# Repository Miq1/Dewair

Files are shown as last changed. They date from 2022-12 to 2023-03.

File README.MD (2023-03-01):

## Multi-purpose environment sensor device

DewAir was originally created to measure temperatures, humidity and dew point inside and outside a room and 
control a ventilator to dry out the room. 
It has been modified in the meantime to accomodate other functions as temperature alarm, remote weather sensor etc.

For this purpose it can be equipped with none, one or two DHT22 sensors, either plugged into the device or detached by a 3-wire cable.
Control over the vent is provided by a relais connected locally or over Modbus TCP to remotely switch a socket.

The device can be configured with a built-in HTML page or over Modbus TCP.
The latter also allows for data retrieval and maintenance. 
If more than one DewAir device is used, one can retrieve the sensor data from another over Modbus TCP, thus saving sensors. 

Power is supplied by USB or 5V, sensors and relais driver are powered internally.
Power consumption is below 90mA normally.

For schematics, PCB designs and 3D printable enclosures see the "Extras" folder.

### Installation

### Usage instructions

#### Start sequence
If powered on, the device will execute some initial steps until reaching normal function.
If it never was configured before (no valid configuration data found) it will immediately start Configuration mode (see next section). 
This is indicated by a slow triple blink pattern of the status LED.

Else there is a short (3s) fast blinking period. If you will press the button within this time, Configuration mode will be entered unconditionally.

Next configuration data is read, a WiFi connection is attempted with the given SSID and password. A fastly blinking LED will signal it.
Once a connection is established, both sensors are checked. If a sensor is found reacting the respective LED will turn on.

At this point the regular state is reached.

#### Configuration mode
In Configuration mode, the device will span its own WiFi network with a name of "DewAir-xxxxxx" and the given password in the source. This by default is "Maelstrom".

You will have to connect to that network to get access to the configuration. Please note that this WiFi is unencrypted and should not be kept online for too long.

Next you will want to open a browser to call the configuration HTML page with URL ``http://192.168.4.1/``. Note again that this is without TLS, so use ``http://``, not "https"!

The configuration page has several parts, described top to bottom below. Most input fields have minimum and maximum values that you may see if hovering over it with your mouse pointer.
The configuration may be invisible in parts at the first time, necessary detail input fields will be swapped in or out depending on your settings.

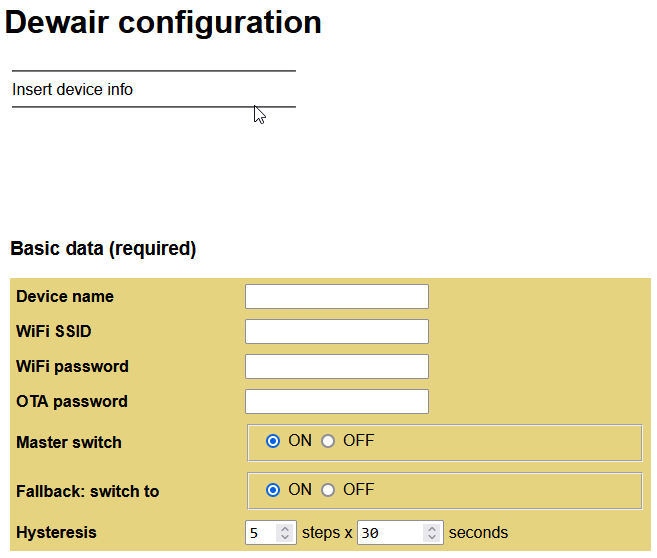
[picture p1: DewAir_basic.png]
Basic data

The most important part is the first, where you will have to enter a name of the new device and the WiFi credentials of your local WiFi for the device to connect to.
Below that you may give an OTA password in case you are planning to update the firmware over air.

The next is the "master switch". This is used to completely switch the logic and target switching on or off. With it you may temporarily disable the device's activities for re-configuration etc. It is advisable to leave it OFF for the first time you are configuring it to be able to cross-check your configurations before going live.

Next comes the "fallback policy". This is to set a default target state in case the sensors or logic will fail at some time.
If set to ON, a failure will drive the device to unconditionally switch the target to ON.
The device logic may be resumed as soon as the causing failure is gone again.
The advisable state of the fallback switch is totally up to you and your application. A frost protector f.i. may better be switched ON, while a motorized door may have to be OFF instead.

Finally the "hysteresis" can be adjusted. Hysteresis means defining a number of necessary, consecutive measurements, whose results have lead to the same logic decision to switch the target.
Hysteresis consists of two components: a number of measurements in a row necessary and the time between measuring actions.
To give an example: a number of 5 measurements and a time of 20s will require the logic to decide the same for all 5 checks in 100s.
Only if all 5 resulted in either all ON or all OFF decisions, the switch finally will be done, if applicable.
The intended result is a less "nervous", steady switching behaviour that does not react on single dropout measurements.

Target configuration
The target definition is required should you want to physically switch something on or off based on the sensor data.
If the device is used as a temp/humidity sensor only, the target may be left unconfigured.
A target may be one of three variants: "ignore", if not relevant as described before, "connected", if the device's relay port is used for it, or "Modbus" for a remote "[Smartdose](https://github.com/eModbus/Smartdose)" socket addressed via Modbus.
To use the latter, the TCP IP address, Modbus port number and Modbus server ID for it are required.

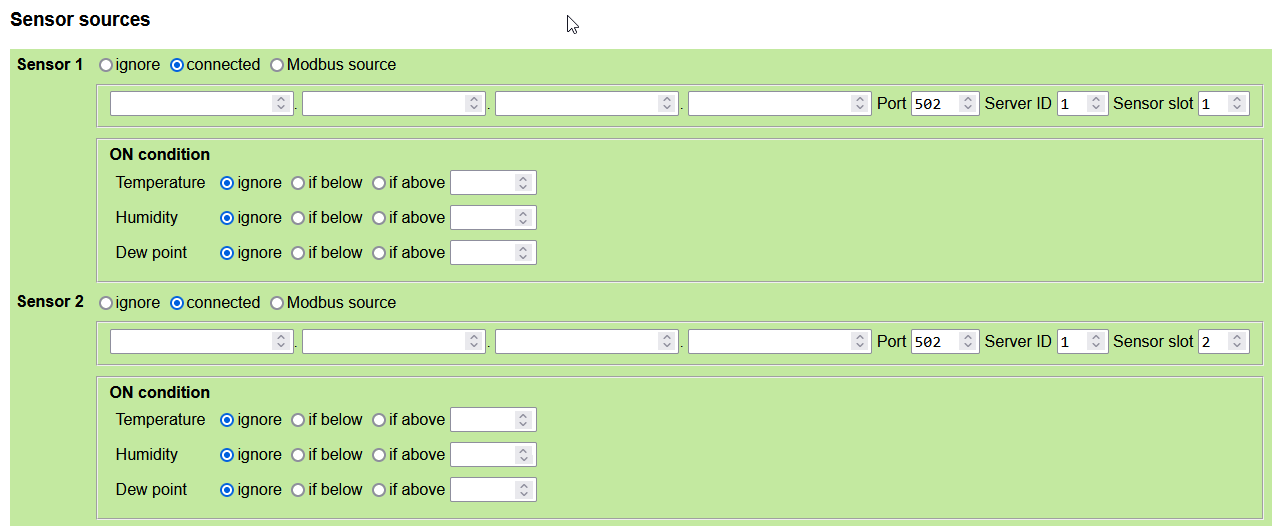
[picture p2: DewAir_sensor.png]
Sensors configuration

Sensor configuration is quite similar to that of the target device.
The "ignore" option leaves the respective sensor slot unregarded. At the same time the combo conditions (see below) will vanish, since 
these only make sense with two sensors present.

The data for a remote, Modbus-connected sensor are the same as before for the target, with one addition: sensor slot.
A remote sensor must reside in another DewAir device to be addressed. As there are two sensor slots, you will need to name the one you are referring to.

A typical application for a remote sensor is to have just one sensor outside the building and all other devices inside it referring to the values of that one sensor.

The conditions section allows to set the conditions the respective sensor must detect to enable the target to be switched on.
Temperature, humidity or dew point can be addressed separately, the results of the evaluations are combined by a logical "and".
If you f.i. want to switch the target on a temperature higher than 10&#176;C and do not care about humidity or dew point, you will want to click on "above" in the temperature line and enter a value of 10 in the data input field. 
Both humidity and dew point options need to be set to "ignore".

Conditions set for a device that later was set to "ignore" as a device will remain unconsidered.

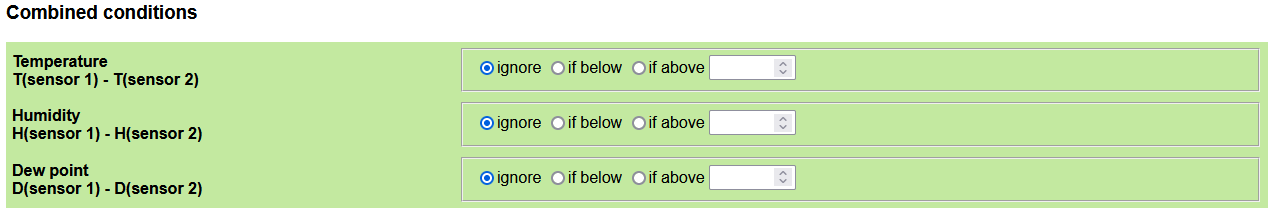
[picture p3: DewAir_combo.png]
Combo conditions

Likewise the combination conditions can be set. There always is a difference of the respective measurement of sensors S0 and S1 taken as the criteria for the conditions.
The settings for the conditions are identical to those with the individual sensor conditions.

#### LED decoding
There are four LEDs on the device in this order: status, S0, S1 and target. 
I recommend to use a different LED color for the status LED for better recognition.

##### Status LED
It will signal the general state the device is in. The start sequence is described above.

In manual mode the status LED will be steadily on, the target LED will show the switch state of the target.

If the target is supposed to be off as result of the evaluation of the conditions, the status LED will display a slow single blinking pattern.

Else, if the target is to be on, the status LED will send a triple blink with a pause in between.

Whenever a measurement is initiated, the status LED will turn on and off after it.

##### Sensor LEDs S0/S1
The respective sensor LED will turn on, if the sensor was configured and a measurement was successful.
A sensor not configured will be displayed by its LED being constantly off.

If a sensor was not responding, the LED will start blinking very quickly. It will resume the regular pattern as soon as the sensor responded again.

##### Target LED
For remote (Modbus) targets, the LED will behave like the sensor leds do: steady on for responding target, quick blinking when the target did not react.

A local target has no such diagnosis, but its state (on or off) will be shown by the LED being lit for ON and dark for OFF state.

#### Button functions
Besides the special interaction during startup (see above for the start sequence) the push button has three different applications.

- Quick press<br/>will start a check of the sensors and target, if any, like is done repeatedly while the device is running.
- Long press<br/>starts manual mode. In it, the sensors are ignored and further short presses will switch the target on and off in turns.
  Another long press will end manual mode and return to automatic control.
- Double click<br/>the conditions for sensor S0, S1 and the combination conditions are checked. If the respective conditions are met,
  the respective sensor LED will light. The target LED stands for the combination conditions.

### Modbus register map

| Register address | type | Contents | Write? | Remarks |
| ---:| ---- | --- |:---:| --- |
| 1 | uint | Master switch | YES | Disable switching logic |
| 2, 3 | float  | S0 temperature  | | DHT22 sensor 0 |
| 4, 5 | float  | S0 humidity | | |
| 6, 7 | float  | S0 dew point | | |
| 8, 9 | float  | S1 temperature  | | DHT22 sensor 1 |
| 10, 11  | float  | S1 humidity | | |
| 12, 13  | float  | S1 dew point | | |
| 14 | uint | Switch state | |  Current target switch state |
| 15 | uint | Restart count | |  Number of reboots since last init |
| 16 | uint | Run time in minutes | |  Minutes since last reboot. Will halt at 65535. |
| 17 | uint | S0 health | |  Each '1' bit stands for a successful read |
| 18 | uint | S1 health | | |
| 19 | uint | Target health | | |
| 20 | uint | Measuring interval in seconds | YES | Must be 10 &le; n &le; 3600 |
| 21 | uint | Hysteresis steps | YES | Must be 1 &le; n &le; 16 |
| 22 | uint | S0 type | YES | 0: none<br/> 1: connected locally<br/> 2: ModbusTCP source<br/> 3: reserved |
| 23, 24  | byte[4] | S0 Modbus IP address | YES | MSB first |
| 25 | uint | S0 Modbus port number | YES | Must be &ge; 1 |
| 26 | byte[2] | MSB: S0 Modbus server ID<br/>LSB: slot number | YES | 1 &le; MSB &le; 247<br/> LSB: 0 or 1 |
| 27 | special | S0 temperature condition:<br/> bits 14,15: condition type<br/> bits 0..13: compare value | YES | *type:*<br/> 0: disregard<br/> 1: less than value<br/> 2: greater than value<br/>3: reserved<br/>*value:*<br/> ``float val = (int(value) - 2048) / 10.0;``|
| 28 | special | S0 humidity condition/value (as above) | YES | see above |
| 29 | special | S0 dew point condition/value (as above) | YES | see above |
| 30 | uint | S1 type | YES | see S0 type |
| 31, 32  | byte[4] | S1 Modbus IP address | YES | MSB first |
| 33 | uint | S1 Modbus port number | YES | Must be &ge; 1 |
| 34 | byte[2] | MSB: S1 Modbus server ID<br/>LSB: slot number | YES | 1 &le; MSB &le; 247<br/> LSB: 0 or 1 |
| 35 | special | S1 temperature condition:<br/> see S0 | YES | see S0 |
| 36 | special | S1 humidity condition/value (as above) | YES | see above |
| 37 | special | S1 dew point condition/value (as above) | YES | see above |
| 38 | uint | Target type | YES | 0: none<br/> 1: connected locally<br/> 2: Modbus TCP target<br/> 3: reserved |
| 39, 40  | byte[4] | Target Modbus IP address | YES | MSB first |
| 41 | uint | Target Modbus port number | YES | Must be &ge; 1 |
| 42 | uint | Target Modbus server ID | YES | **MSB only!**<br/> Must be 1 &le; SID &le; 247 |
| 43 | special | (S0 temperature - S1 temperature) condition type and value | YES | see S0 temperature condition and type above |
| 44 | special | (S0 humidity - S1 humidity) condition type and value | YES | see above |
| 45 | special | (S0 dew point - S1 dew point) condition type and value | YES | see above |
| 46 | uint | nibble 0: number of combo conditions met<br/>nibble 1: number of S1 conditions met<br/>nibble 2: number of S0 conditions met<br/>nibble 3: unused | | debug info |
| 47 | uint | Fallback switch setting | YES | 0: OFF<br/>else: ON |
| 48 | uint | Number of history slots | | 1440 minutes a day / slots = minutes within a slot for values to be averaged |
| 49 | uint | Start address of first history slot entry | | see section below! |
| 50 | uint | Currently written history data slot | | see below! |
| 51 .. 63 | | *reserved* | YES | future extension space |
| 64 | uint | Number of event slots | | if 0: no events available |
| 65 .. | special | Logged events (number see register 64) | | bits 11 .. 15: Event code<br/>bits 6 .. 10: day/hour<br/>bits 0 .. 5: month/minute |

#### History entries
For each history slot, temperatures and humidities of both sensors (if available) are averaged over the values within that slot.
The slots are ordered from 0=00:00 to (history slots - 1)=last before midnight.
Times as are related to slots can be calculated as follows:
- 1440 / history slots = minutes per slot. The default 120 slots translate to 12 minutes per slot.
- A given slot number needs to be multiplied by the minutes per slot, then has to be separated into hour and minute.
  Example: slot 67 is 67 * 12 = 804 minutes since midnight. Divided by 60 this is 13 hours. The remainder are 24 minutes.
  Hence the slot 67 is starting at 13:24 (1:24pm).
To fit into an ``uint16_t`` register, values are encoded:
- temperature: (avg(temp) + 100) * 10. ``1256`` will mean 25.6 degrees.
- humidity: avg(hum) * 10. ``489`` stands for 48.9% RH.
Additionally the percentage of the target being on is collected.
All time ON withing the slot is 100%, never ON is 0%.

| Register address | type | Contents | Write? | Remarks |
| ---:| ---- | --- |:---:| --- |
| History offset..history offset + history slots - 1 | uint | Sensor 0 temperature history values |  | encoded as described above |
| like the above, History slots added | uint | Sensor 0 humidity history values |  | encoded as described above |
| like line 1, 2 * History slots added | uint | Sensor 1 temperature history values |  | encoded as described above |
| like line 1, 3 * History slots added | uint | Sensor 1 humidity history values |  | encoded as described above |
| like line 1, 4 * History slots added | uint | Target switch ON percentage |  | see section above |

### Applications

#### Dew point ventilation

#### Frost protection

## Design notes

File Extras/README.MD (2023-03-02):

# Extras
This folder contains additional components and materials I developed for my DewAir devices - namely, the dew point ventilation controller and the frost protection device.

- Enclosure contains FreeCAD 3D designs and STL files for a small and a large box. The small one is powered by USB or 5V and needs a WiFi socket as target device, the larger box has all inside to run autonomously when connected to a wall power outlet.
- Fan Mount has 3D FreeCAD designs and STLs as well for attaching a 100mm standard tube ventilator or a 100mm air gauge to a window pane. I replaced the glass panes by acrylic glass and cut a hole in in to fit the mount. A drilling/cutting template can be 3D printed as well.
- PCB holds all KiCAD and Gerber files necessary to have the PCB manufactured.
- ``DewAir.cpp`` is a Linux command line tool to configure and control any DewAir device. It requires the Linux port of the [eModbus](https://github.com/eModbus/eModbus) library to be built - found there in the [examples/Linux](https://github.com/eModbus/eModbus/tree/master/examples/Linux) directory.
See below for build instructions etc.

### DewAir Linux tool
All interaction with the device is done by Modbus TCP. 
You of course may use other Modbus TCP clients to achieve the same, but you will need to closely inspect the Modbus register list for it.
The ``DewAir`` tool has all the definitions built in and lets you use plain text words to interact with the device.

#### Build and Install
As a prerequisite you will need to build the Linux eModbus library as mentioned in the first section.
With that available you can compile the program by
```
g++ DewAir.cpp -Wextra -DLOG_LEVEL=3 -MMD -leModbus -pthread -lexplain -o DewAir
```
#### Usage
Running ``DewAir`` without any parameter will display the supported options:
```
micha@LinuxBox:~$ DewAir 
At least one argument needed!

Usage: DewAir host[:port[:serverID]]] [cmd [cmd_parms]]
  cmd: INFO | ON | OFF | EVERY | EVENTS | INTERVAL | HYSTERESIS | TARGET | SENSOR | CONDITION | FALLBACK | REBOOT | ERRORS | HISTORY
  ON|OFF
  FALLBACK ON|OFF
  EVERY <seconds>
  EVENTS
  ERRORS
  HISTORY
  INTERVAL <seconds>
  HYSTERESIS <steps>
  TARGET NONE|LOCAL|<host[:port[:serverID]]]>
  SENSOR <0|1> NONE|LOCAL|<<host[:port[:serverID]]]> <0|1>>
  CONDITION <SENSOR <0|1>>|DIFF TEMP|HUM|DEW IGNORE|<BELOW|ABOVE <value>>
  REBOOT
```
``DewAir`` needs a device as first parameter in any case.
This can be the DNS name the device has been assigned, or a detailed address consisting of an IP address, a port number and a Modbus server ID, separated by colons (':').
If omitted, the server ID defaults to 1, the port number is 502 by default.

After the address of the device a command is expected. If none was given, ``INFO`` is taken as a default.

#### INFO
With ``INFO`` the current data is requested from the device. Sample output:
```
micha@LinuxBox:~$ DewAir anbau 
Using 192.168.178.30:502:1
Master switch ON
Fallback: switch ON
Sensor 0:  12.1°C   56.0%    3.6°C  - FFFF
Sensor 1:   6.4°C   45.8%   -4.4°C  - FFFF
Target is OFF - FFFF 192.168.178.40:502:1
Measuring every 30 seconds, hysteresis steps: 4
86 restarts, run time since last restart 24:48
40 event slots
120 history slots starting at 400, current is 83
Switch conditions (all must be true): 
 + S0 temperature below   5.0°C
Condition state: 0233
```
You see how the DNS name ``anbau`` is translated internally to a full address.
The device is active (master is ON), on failures it will switch the target to ON.
Both sensors are connected locally and are performing well (``FFFF`` tells us the last 16 sensor requests were successful).
The target device is a Modbus-controlled remote socket, it is currently OFF and communication was okay (``FFFF`` again).
Sensors are requested every 30 seconds and 4 consecutive identical evaluations of the conditions set will trigger a switching action.
The device was restarted 86 times and is running more than a day now after the last restart.
It does register the last 40 events (see below) and the data history has 120 time slices over a day. Modbus register 400 holds the first history value.
The device is set to switch the target as soon as sensor 0 will report a temperature below 5 degrees. Current temperature is above that, so the state is not ``0333`` as it would be with all conditions met.

#### ON/OFF
This will activate or deactivate the device. The 'Master switch' is turned ON or OFF.
If set to OFF, the device will work as normal, but never will touch the target's state.

#### FALLBACK
If sensors have malfunctions or are not responding, there is no reliable evaluation of the switch conditions possible any more.
``FALLBACK`` defines the target state that will be set in such situations.
F.i. a frost protection device may set to fall back to ON state to prevent freezing - for the cost of unnecessary energy wasted.

#### EVERY
``EVERY`` will request and print out the sensor and target state values in the intervals given as additional seconds parameter.
Note that this value must be 60 or higher to prevent the device being flooded with requests.
The output is a comma separated list for easy processing in a spreadsheet program. To have an output readable on the terminal you should pipe it through a ``tr`` like in
```
micha@LinuxBox:~$ DewAir anbau every 60 | tr ';' '\t'
Using 192.168.178.30:502:1
Time    S0                      S1                      Diff                    target
        temp    hum     dew     temp    hum     dew     temp    hum     dew
17:25   12.2    53.0    2.9     5.6     47.2    -4.8    6.6     5.8     7.7     0
```
Output can be stopped by ``Ctrl C`` only.

#### EVENTS
Important things happening will be recorded on the device in the ``EVENTS`` list. It looks like
```
micha@LinuxBox:~$ DewAir anbau events
Using 192.168.178.30:502:1
40 event slots found.
target off           18:06
target off           20:05
target off           20:06
target off           22:05
target off           22:06
date change     01.03.
target off           00:05
target off           00:06
target off           01:09
target off           02:05
target off           04:05
target on            04:49
target off           04:54
target on            05:28
...
```
(Note: in this example the target itself is programmed to turn on every two hours, so as soon as the DewAir device notices the target being ON, it will switch it OFF again).

#### ERRORS
Similar to the events, Modbus errors are recorded on the device.
With the ``ERRORS`` command you may retrieve what was stored:
```
micha@LinuxBox:~$ DewAir anbau errors
Using 192.168.178.30:502:1
Back : ERR  Count
    0:  00    229 - Success
    1:  E0      1 - Timeout
    2:  00    410 - Success
    3:  EA      1 - IP connection failed
    4:  00    937 - Success
```
Only if the Modbus state has changed a new entry is made. Else only the number of occurrences of the same state will be counted.
Note that the most recent state is shown on top, the lower, the older the stes are.

#### HISTORY
All sensor data and target states are collected for 24h. Values older will be replaced by current values as time proceeds.
The data is averaged over time slots. A slot is 12 minutes wide in the default code.
Hence you will have 120 slots per 24h that can be retrieved in a single Modbus request.
There are 120 such values for sensor 0 temperature, humidity, sensor 1 temperature and humidity and the target state value. 
A complete history data set will have 600 values, each in a Modbus register.
Floating point sensor values are encoded to fit into the 16 bits of a Modbus register.
The coding scheme is described on the main page - see section 'History' there.

The ``HISTORY`` command will do all 5 requests and the decoding in one step and outputs the data as a comma-separated list to be processed in a spreadsheet program.
It is advisable to catch the output in a file and open it in a spreadsheet:
```
micha@LinuxBox:~$ DewAir anbau history > anbau.csv
```
With a bit of massaging in the spreadsheet you can quickly get some nice diagrams:

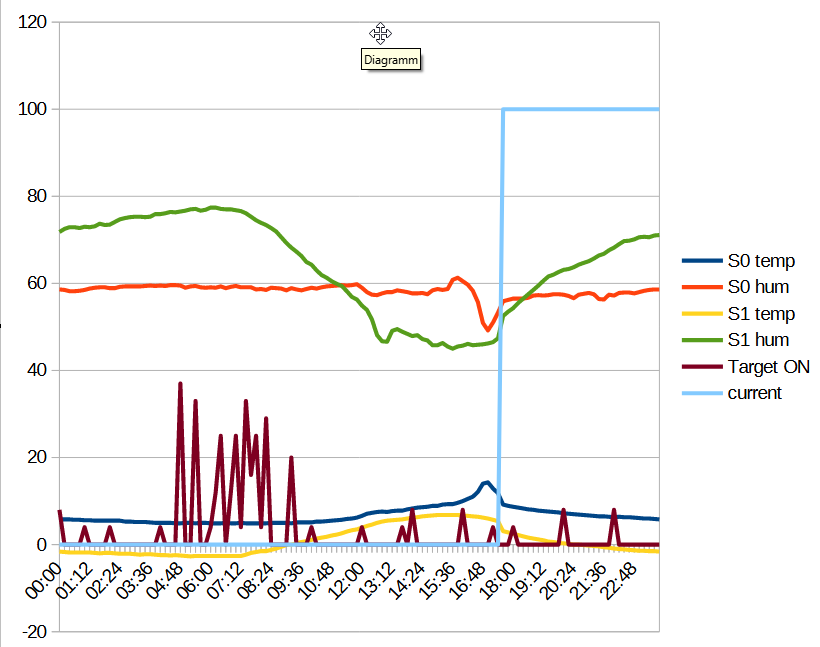
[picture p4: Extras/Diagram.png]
Sample diagram


A sixth column is added to the output that is almost empty. The exception is a ``#`` sign in that row where the next slot will be written.
So right of that line is data from the previous day, left of it the data for the current day up to now.

In the diagram above I used a simple formula (``=IF($H3=" ";$G2;100)``) to have a line jump up at the current slot. It will take a zero as start value and always replicate the value of the line above - except if the neighbouring cell has something other than a blank in it; then the value will set to 100.

#### REBOOT
A mechanism has been integrated to remotely restart a DewAir device. 
It makes use of the user-definable Modbus function code 0x44.
``REBOOT`` has to be sent twice within 60 seconds to have an effect. 
This is meant as a basic security mechanism. 
The first ``REBOOT`` will be answered by ``armed.``, the second, if received within the 60s period, will print out ``rebooting.``.
If the second commend is late or not given at all, the ``armed`` state will be reset on the device.

#### INTERVAL ``<seconds>`` and HYSTERESIS ``<turns>``
These two commands will modify the reaction speed of the device on changing sensor data.
Data is sampled every ``INTERVAL`` seconds. Note that the seconds parameter can not be lower than 20 to not overload the device.

``HYSTERESIS`` sets a number of sampling periods where the sampled values are fulfilling the switching conditions without exception.
If that happens, a switch is executed.

F.i. a combination of 30 seconds and a hysteresis of 6 will require the switch conditions to last at least 3 minutes to trigger a switch.
Higher values will lead to a slower, smoother switching behaviour, whereas short intervals or less hysteresis periods will let the device react more quickly.
It depends from your application which may be the adequate setting.

#### TARGET
The ``TARGET`` command lets you define if there is a switching target at all and what type it is.

A ``TARGET NONE`` will disable any switching actions, while sensor data still is collected.
This may be useful if you are using a DewAir device as a remote temperature/humidity platform to read these data and make it available to other devices.
Please see the ``SENSOR`` explanations in the section below.

``TARGET LOCAL`` enables the device to use the internal relay/SSR logic as a target. 
A stand-alone DewAir device may switch a built-in socket this way.

Finally ``TARGET <Modbus address>`` allows for remote target devices that can be switched by a Modbus request.
At this time only the [Smartdose](https://github.com/eModbus/Smartdose) type of devices is supported. 
Other WiFi sockets will need a different command or even different protocol that would have to be integrated first.
Contributions are always welcome... :wink:

The Modbus address needs to be given as described above for the first parameter of the DewAir application itself: either a DNS name or a set of IP address, port and server ID, joined by colons ':'.

#### SENSOR
Each of the two attachable sensors may be non-existent, plugged in locally into the device or other DewAir devices in the same local network.

``SENSOR`` always needs a sensor number first, that can be ``0`` for the first or ``1`` for the second DHT22 sensor.

After that we can have ``NONE`` to disable the sensor slot, ``LOCAL`` for sensors connected by wire to the device, or a Modbus address again to connect to another DewAir device.

The Modbus address has to follow the very same rules as described above for the DewAir application or the ``TARGET`` parameter.
It requires one more parameter after it, though: the sensor slot on the remote device.
This slot addresses the two sensors on that device the same way as we are doing here: ``0`` is the first, ``1`` the second sensor.

Instead of collecting the data locally, a remote sensor will be requested by Modbus. 
Note that due to the communication delays and collecting interval on the remote device the data gathered remotely may not exactly be measured at the same time the request was sent, but will be delayed for some seconds.

#### CONDITION
If and when a target gets switched is depending from the conditions you have defined in regards to the sensor data.
The ``CONDITION`` command lets you set these conditions at will.

First you will have to tell what conditions you are going to set:
- ``SENSOR 0`` or ``SENSOR 1`` will select the respective sensor
- ``DIFF`` instead will target on conditions for both sensors combined. Note that this is not possible if one or both sensors are set to ``NONE``!

The next parameter selects the data type you are using for the condition - ``TEMP`` for temperature, ``HUM`` for humidity or ``DEW`` for the dew point temperature evaluated internally.

Last is the condition proper:
- ``IGNORE`` disables it to not be regarded any more
- ``BELOW <value>`` will result ``TRUE`` if the selected data is lower than the given ``<value>``
- opposite, ``ABOVE <value>`` will be ``TRUE`` if the data is higher than ``<value>``

Example:
```
DewAir condition sensor 0 temp below 5
```
will require the first sensor's temperature to be lower than 5 degrees Celsius to be evaluated to ``TRUE``.

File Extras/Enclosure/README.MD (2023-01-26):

## Enclosures

There is a FreeCAD design currently only for the bare logic board without the relay or power outlet etc. This will be added at a later time.

### Logic board ("DewAir_klein_V2")

The case described here is meant to fit the board with the attached LED part facing backwards. Uses are temperature/humidity sensors to be requested via Modbus or a control device with a target addressed over Modbus. 

#### Parts

Please note the names of the parts are in German - which should not matter at all, I will give the necessary descriptions below.
Also please refer to the picture below!

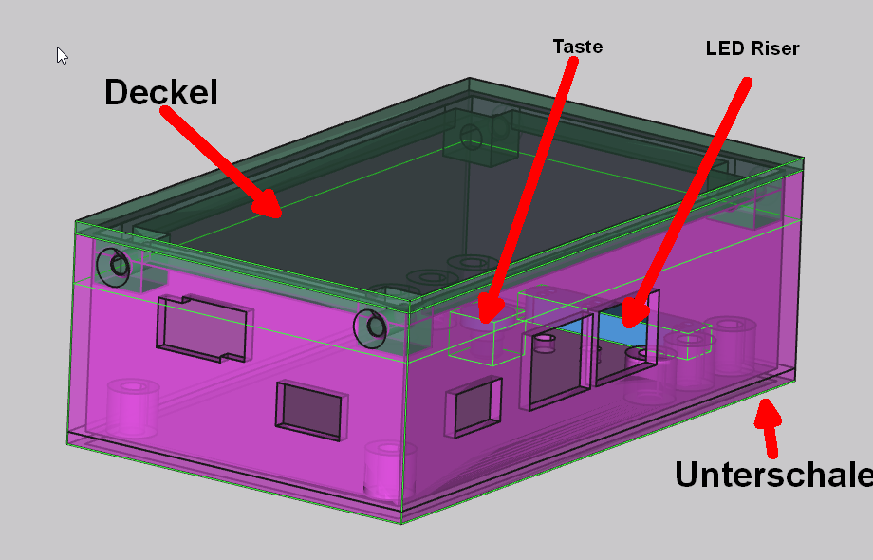
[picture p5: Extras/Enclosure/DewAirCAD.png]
Parts overview


##### Unterschale ("Box")

The Unterschale part is the box proper to hold the PCB. The LEDs and switch are to be soldered to the back side of the PCB, opposite to all other parts.
Holes in the bottom of box will hold the 4 LEDs and button in place.

The openings in the box for sensors 0 and 1, 5V power connector, relay connector and the MCU's USB port are configurable as are required in the FreeCAD file provided.
There is a DynamicData object called "Masse" in the construction, where a "Hasxxx" boolean variable is provided for each opening.
If set to ``true``, the opening will be activated.

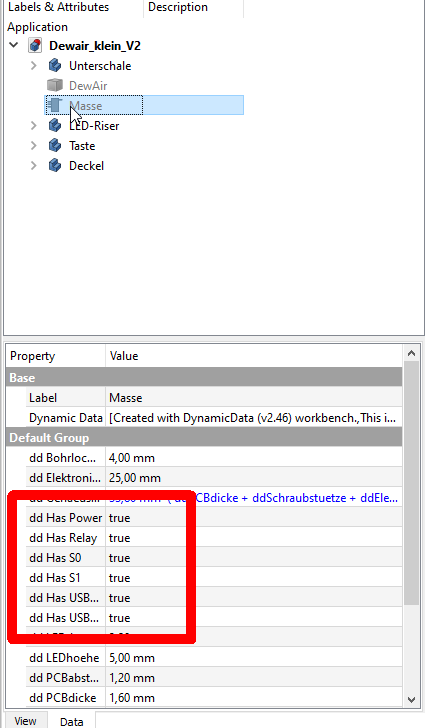
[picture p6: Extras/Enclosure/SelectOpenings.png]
Openings selection


Note there are two ``HasUSB...`` variables that each will match the type of MCU module you are using - NodeMCU or Wemos D1 mini.

##### Deckel ("Lid")

The Deckel part is the closing lid of the box. It will be secured by 4 M3 screws on the corners to the Unterschale part.
Note that there are two STL files for this part. The one called ``...Deckel_Hang.stl`` contains a lid with four fastening tabs attached. 
In the FreeCAD file, these can be activated by setting the ``HasHangers`` boolean variable to ``true``.

##### Taste ("Button")

The Taste part is set into the largest bottom hole in the box and will allow to click the button on the PCB from outside of the box.
It is advisable to print it in a different color than the box to have it stand out.

##### LED-Riser

Since the necessary distance between the PCB and the box needs to be larger than the LEDs' lengths to fit the switch button, LEDs need to be elevated a bit from the PCB when soldered.

The LED-Riser part need to be printed and put in between the LEDs and the PCB before soldering these.

#### Printing

I would recommend to use PETG or ABS for the parts for better resilience of the case. Depending on the environment a PLA case may suffer from UV radiation or wet conditions.

The LED-Riser part needs to be printed first, for it will have to be used when soldering the PCB already.

#### Assembly

Depending on the environment where the device is deployed up to all 8 PCB sockets can be equipped with melt-in threads for maximum stability. 
The minimum would be the 4 sockets at the 4 corners, but I would advise to have the two additional sockets for the LED and button part used as well to prevent the board breaking if too hard a pressure is applied to the button.

First set the Taste part into the matching hole of the box, then put in the PCB, gently guiding the LEDs into their holes.
Fasten the PCB with M3 screws to the sockets.

Insert 4 more melt-in threads into the corner blocks of the Deckel part. Put on the lid and secure it with 4 M3 countersunk screws to the box. The screw heads shall be completely sunk into the box' holes.

### DHT22 housing

This is a little "bird cage" case for the DHT22 temperature/humidity sensors to be attached outside. 
The bottom part may be bolted to a wall, then the DHT22 with cable is laid into it and finally a lid is fastened to it.
Thus you may open the case and take out the sensor without having to unscrew the case from the wall again.
The cable is supposed to go through the S-shaped channel at the bottom to prevent it from being ripped off.
The case has air vent openings facing down to prevent rain coming into the case.

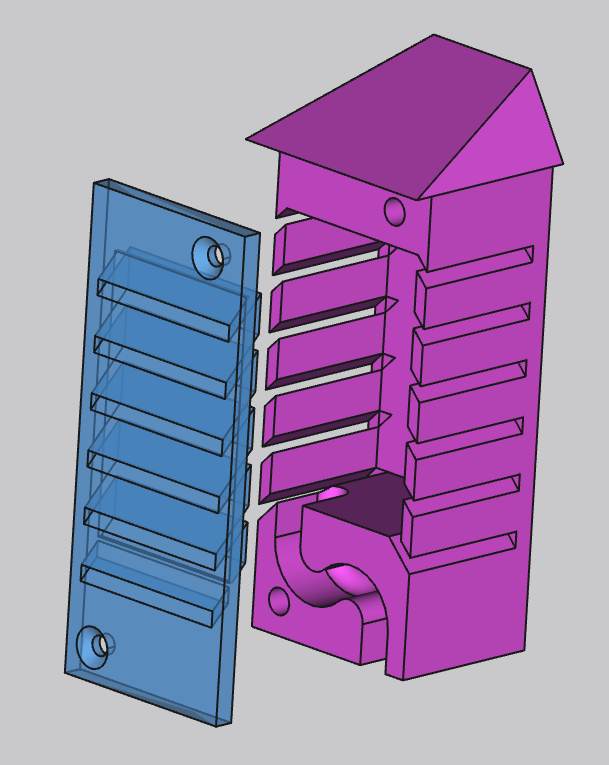
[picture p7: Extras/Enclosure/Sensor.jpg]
Sensor case


### Large enclosure ("Dewair_gross_V2")

The large enclosure fits the logic board plus some components to locally switch and power the target device.

*** URGENT NOTE ***
*** If you are not qualified enough to safely handle the mains power installations, I urgently advise to keep off! ***

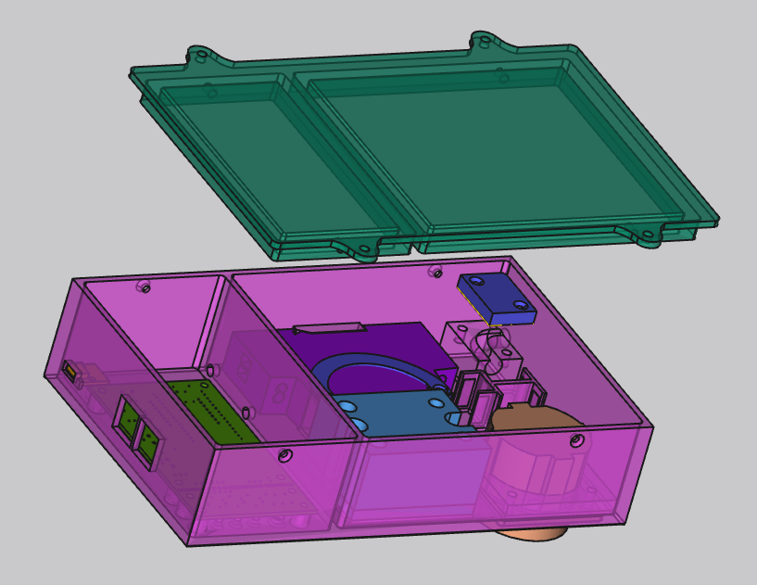
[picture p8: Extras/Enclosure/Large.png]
Large box


This will largely depend from your power line standards etc., so please note that it is currently designed for German 230V sockets etc.
The components are chosen to require no direct soldering or contact with mains; a dedicated power PCB with relay could reduce the space requirements a lot.

Feel free to use the enclosed FreeCAD files to modify it to your needs.

The box as is will fit
- the logic board
- a micro USB port
- a DIN rail 5V/2.4A power supply
- a 40A SSR (solid state relay)
- a standard "Schuko" 230V socket
- cabling etc.

The box and cover parts are exactly matching each other to get a safely closed and sturdy enclosure.
The walls are 3mm wide to support that aim.
As a consequence printing the parts will require about 300g PETG and take quite some time to finish.

#### Application notes

Most of the fixing of parts is done with metric screws, that are supposed to be fastened with melt-in threads of size M3.
The holes in the box are provided for these.

An exception is the USB port, where two 3mm self-cutting screws are necessary.
Please note that you will have to make a micro USB connection cable to the ESP8266 board on the PCB.

The power cord is supposed to be pushed through the L-shaped channel and fixed with the small rectangular lid provided as an extra part.

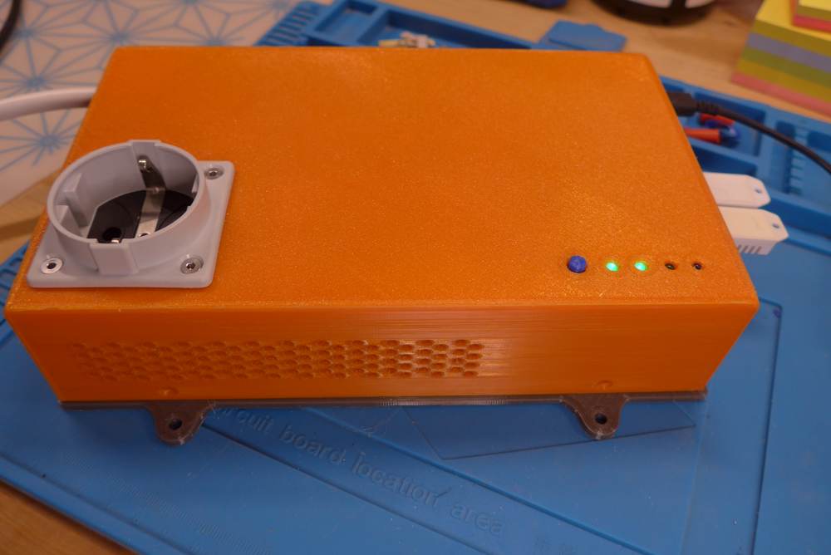
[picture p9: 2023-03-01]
Extras/Enclosure/Large_side.jpg

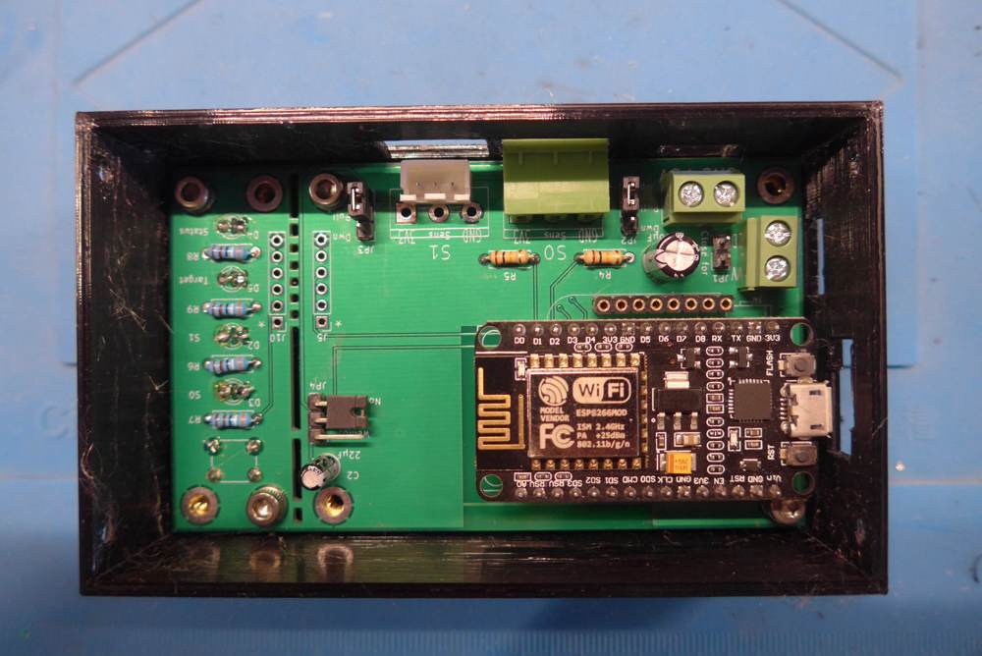
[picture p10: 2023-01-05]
Extras/Enclosure/Open.jpg

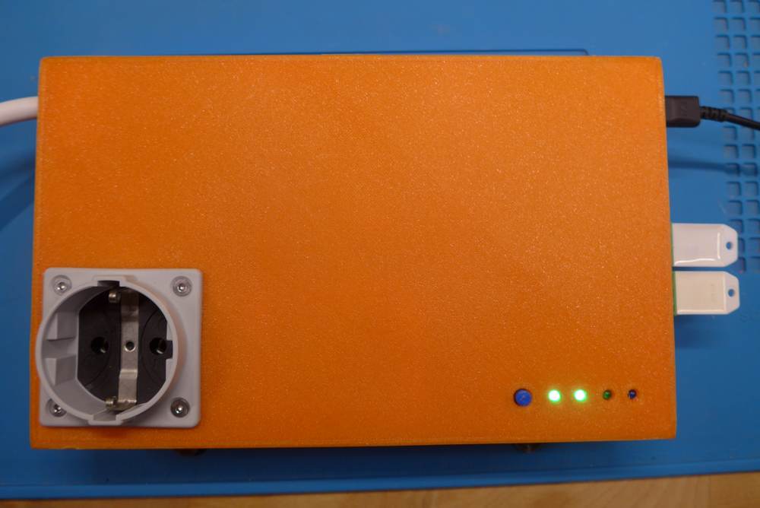
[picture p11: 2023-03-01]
Extras/Enclosure/Large_top.jpg

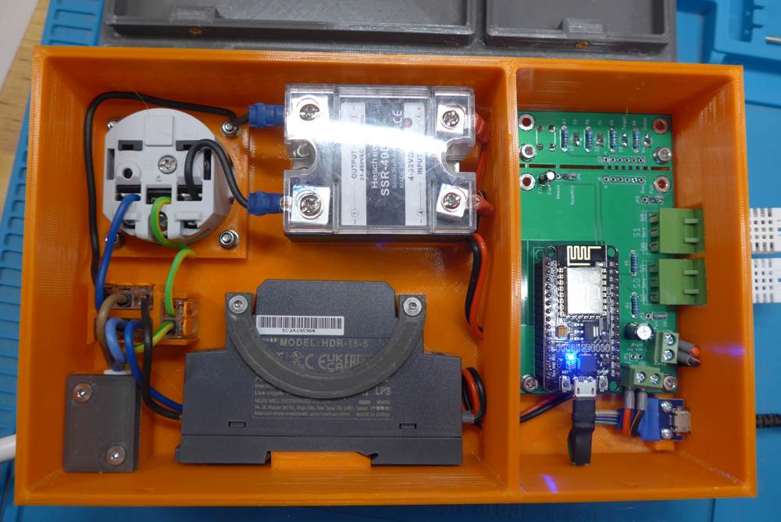
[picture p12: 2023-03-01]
Extras/Enclosure/Large_open.jpg

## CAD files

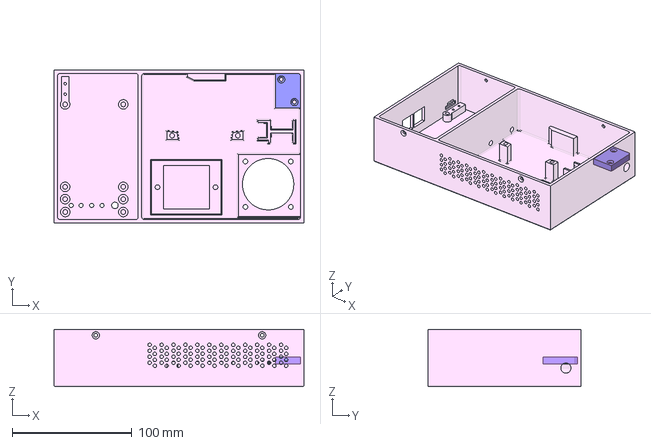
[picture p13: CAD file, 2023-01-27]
Extras/Enclosure/Dewair_gross_V2.FCStd
209.2 x 128.3 x 48.0 mm
PowerCordLock

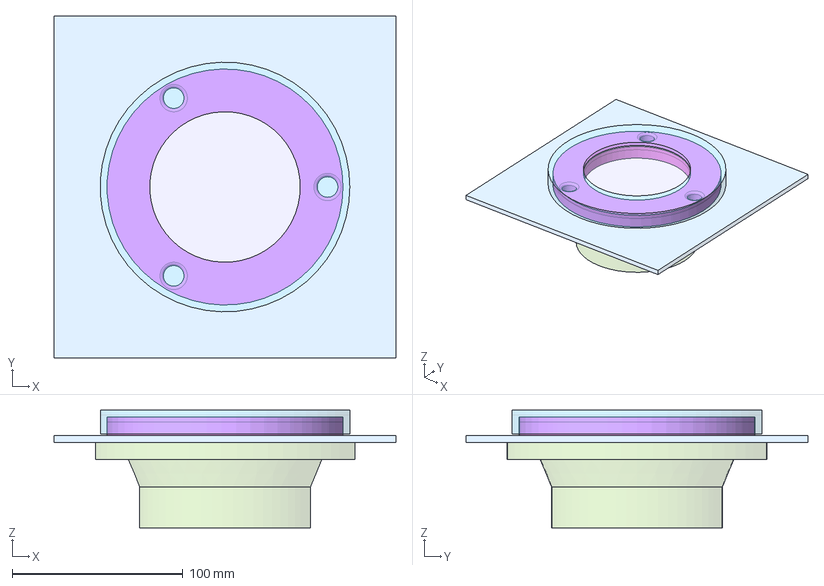
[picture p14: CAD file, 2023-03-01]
Extras/Fan_Mount/Lüfterhalterung.FCStd
200.0 x 200.0 x 69.0 mm
Scheibe
Aussenkranz
Fliegengitter
Abdeckring
Schlauchadapter

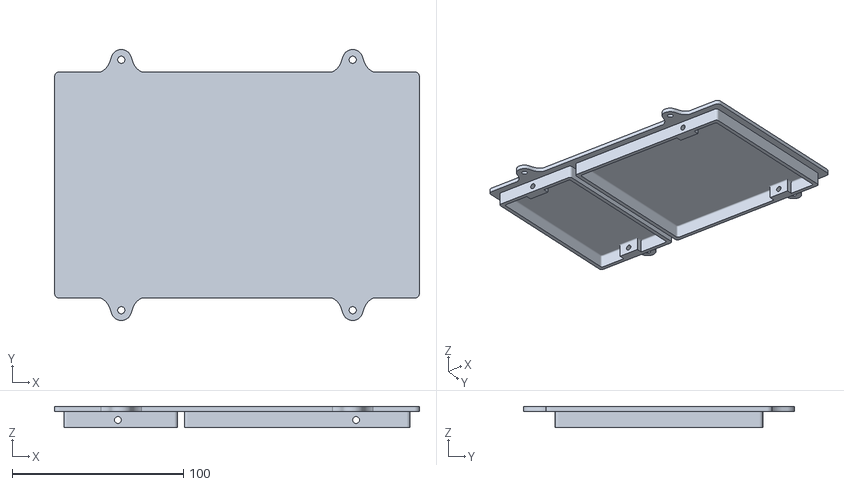
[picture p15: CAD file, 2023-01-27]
Extras/Enclosure/Dewair_gross_V2-Cover.stl
213.2 x 158.3 x 12.5

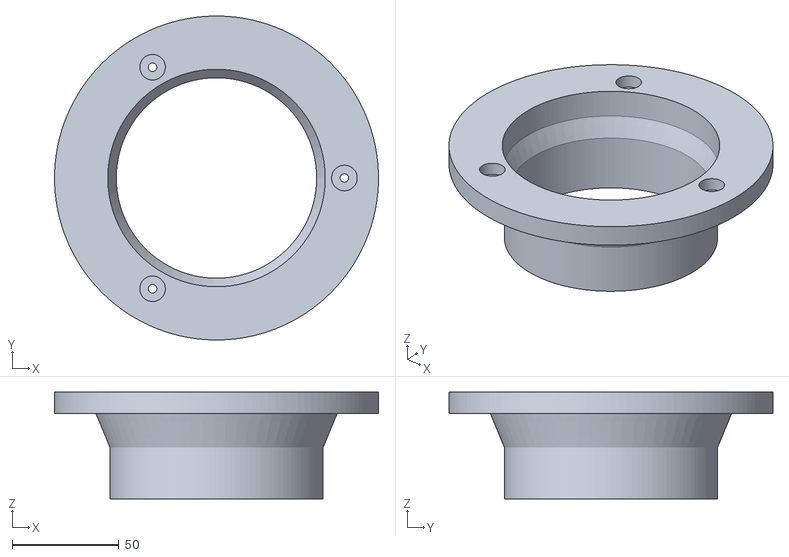
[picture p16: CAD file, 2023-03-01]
Extras/Fan_Mount/Lüfterhalterung-Schlauchadapter.stl
152.0 x 152.0 x 50.0

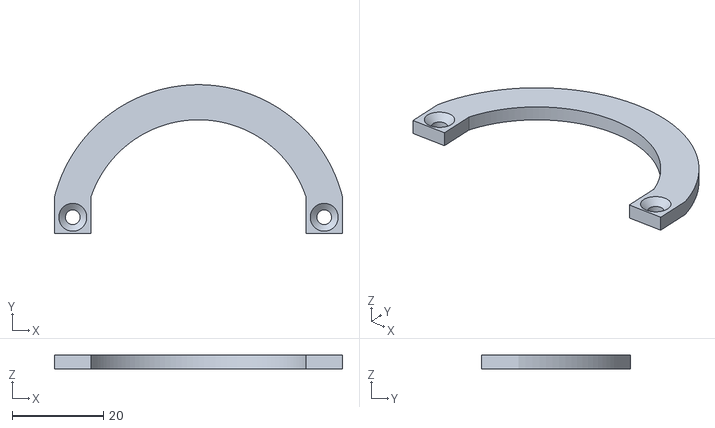
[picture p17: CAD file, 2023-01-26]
Extras/Enclosure/Dewair_gross_V2-Power lock.stl
63.0 x 32.5 x 3.00

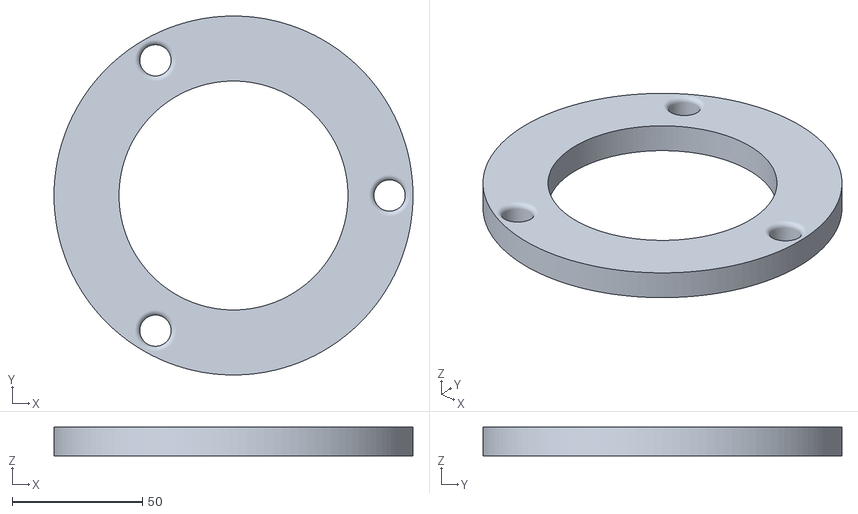
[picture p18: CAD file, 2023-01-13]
Extras/Fan_Mount/Lüfterhalterung-Aussenkranz.stl
138.0 x 138.0 x 11.0

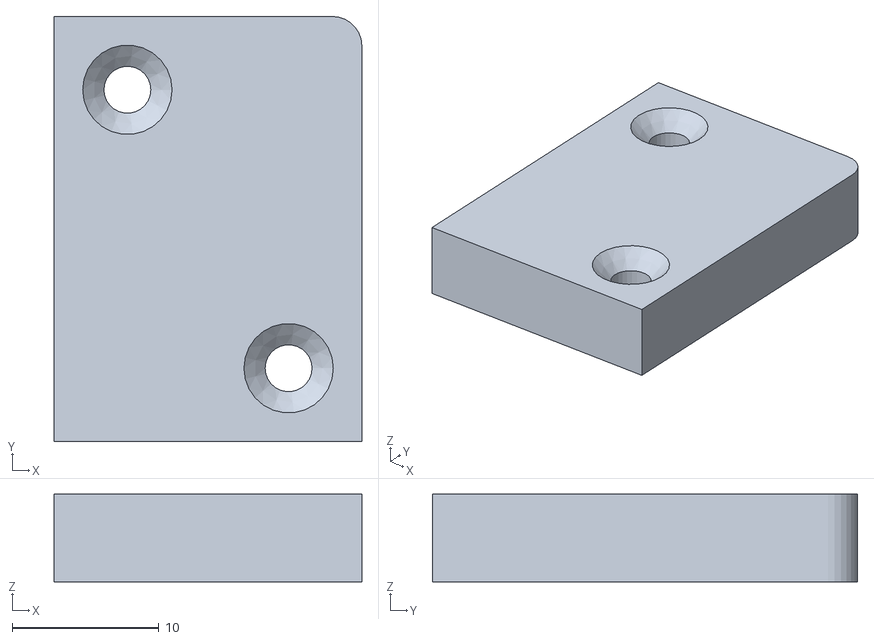
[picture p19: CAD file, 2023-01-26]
Extras/Enclosure/Dewair_gross_V2-PowerCordLock.stl
21.0 x 29.0 x 6.00

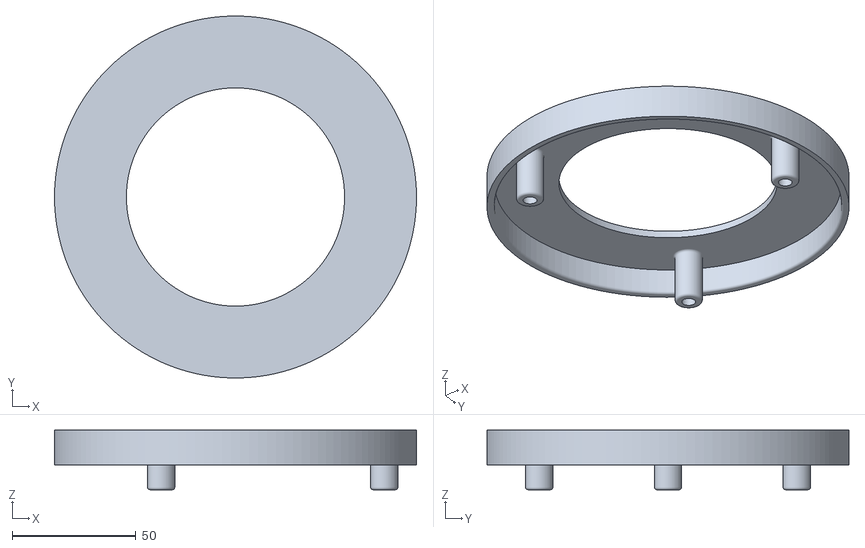
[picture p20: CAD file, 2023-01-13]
Extras/Fan_Mount/Lüfterhalterung-Abdeckring.stl
146.0 x 146.0 x 24.0

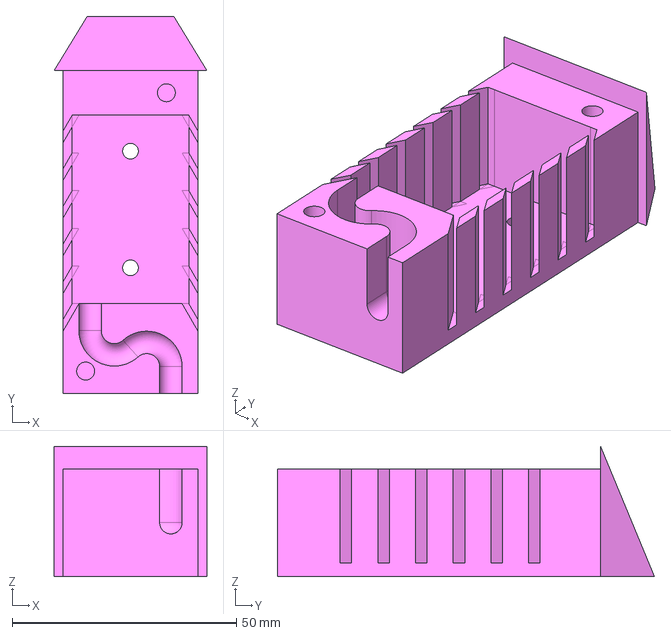
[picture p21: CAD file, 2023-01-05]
Extras/Enclosure/Sensor.FCStd
34.0 x 84.0 x 29.0 mm

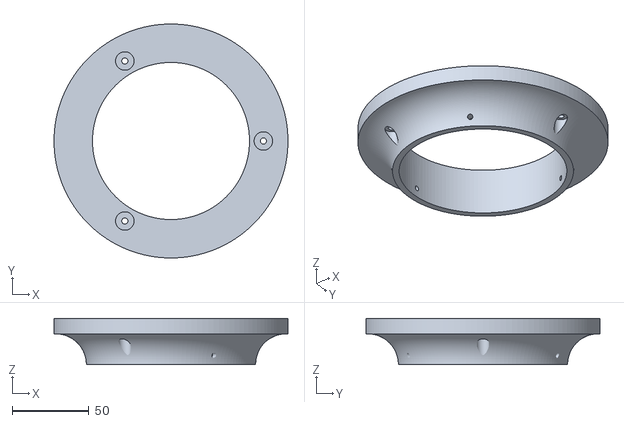
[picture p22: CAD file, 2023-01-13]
Extras/Fan_Mount/Lüfterhalterung-Stuetzring.stl
152.0 x 152.0 x 30.0

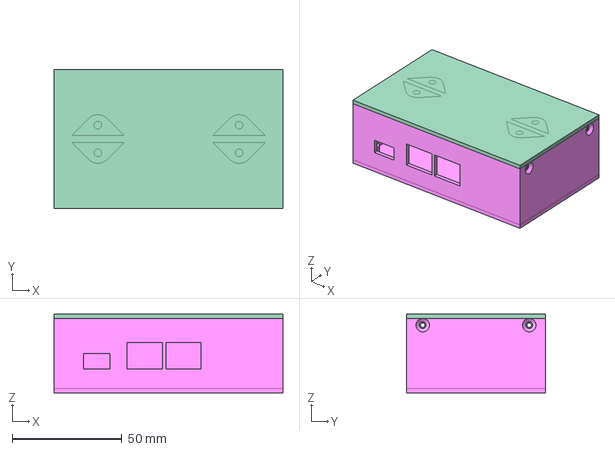
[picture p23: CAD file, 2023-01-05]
Extras/Enclosure/Dewair_klein_V2.FCStd
104.3 x 63.2 x 35.8 mm
Unterschale
Deckel

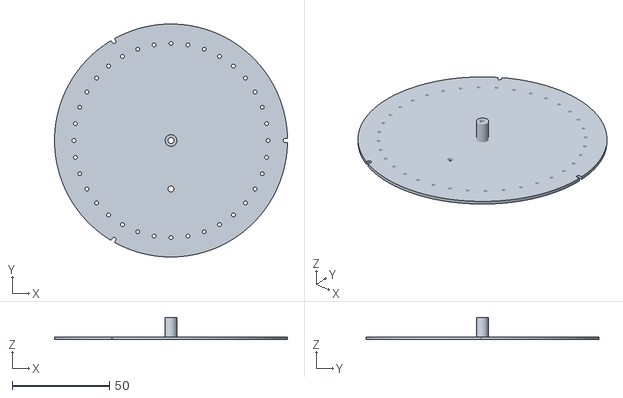
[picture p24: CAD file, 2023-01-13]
Extras/Fan_Mount/Lüfterhalterung-Bohrschablone.stl
120.0 x 120.0 x 11.5

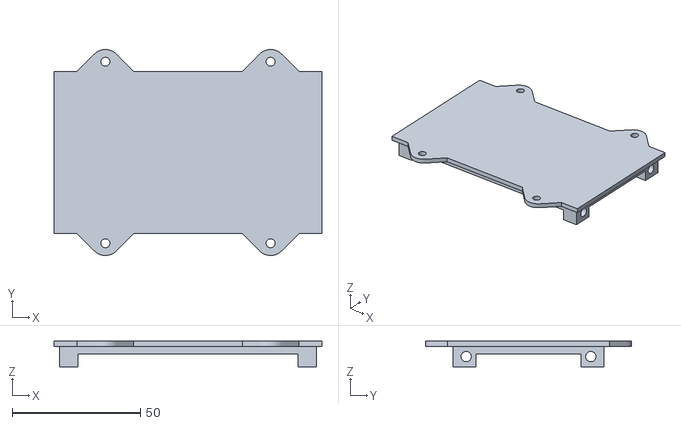
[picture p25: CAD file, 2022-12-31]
Extras/Enclosure/Dewair_klein_V2-Deckel_Hang.stl
104.3 x 80.2 x 10.0

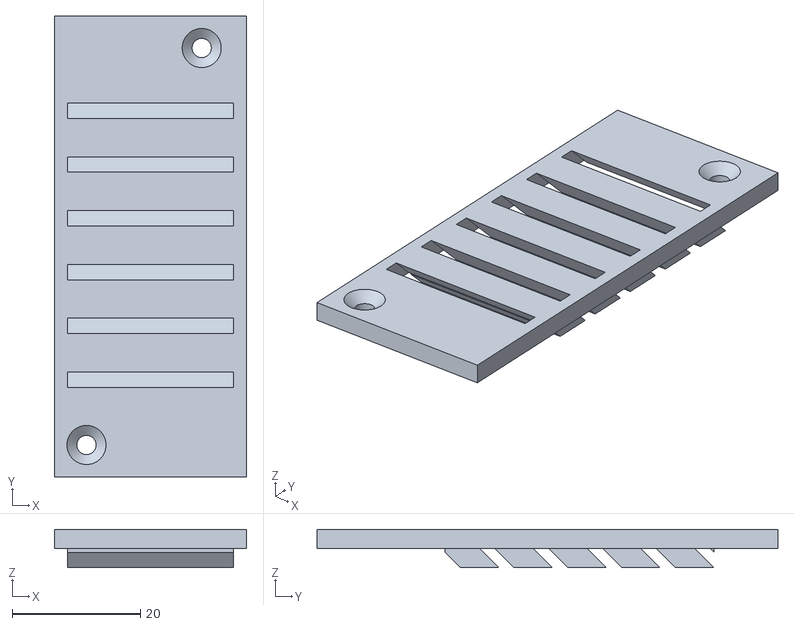
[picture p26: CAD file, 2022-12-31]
Extras/Enclosure/Sensor_Deckel.stl
30.0 x 72.0 x 6.00

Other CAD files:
Extras/Enclosure/Sensor_Gehaeuse.stl
Extras/Enclosure/Dewair_klein_V2-Deckel.stl
Extras/Enclosure/Dewair_klein_V2-Unterschale.stl
Extras/Enclosure/Dewair_klein_V2-LED-Riser.stl
Extras/Enclosure/Dewair_klein_V2-Taste.stl

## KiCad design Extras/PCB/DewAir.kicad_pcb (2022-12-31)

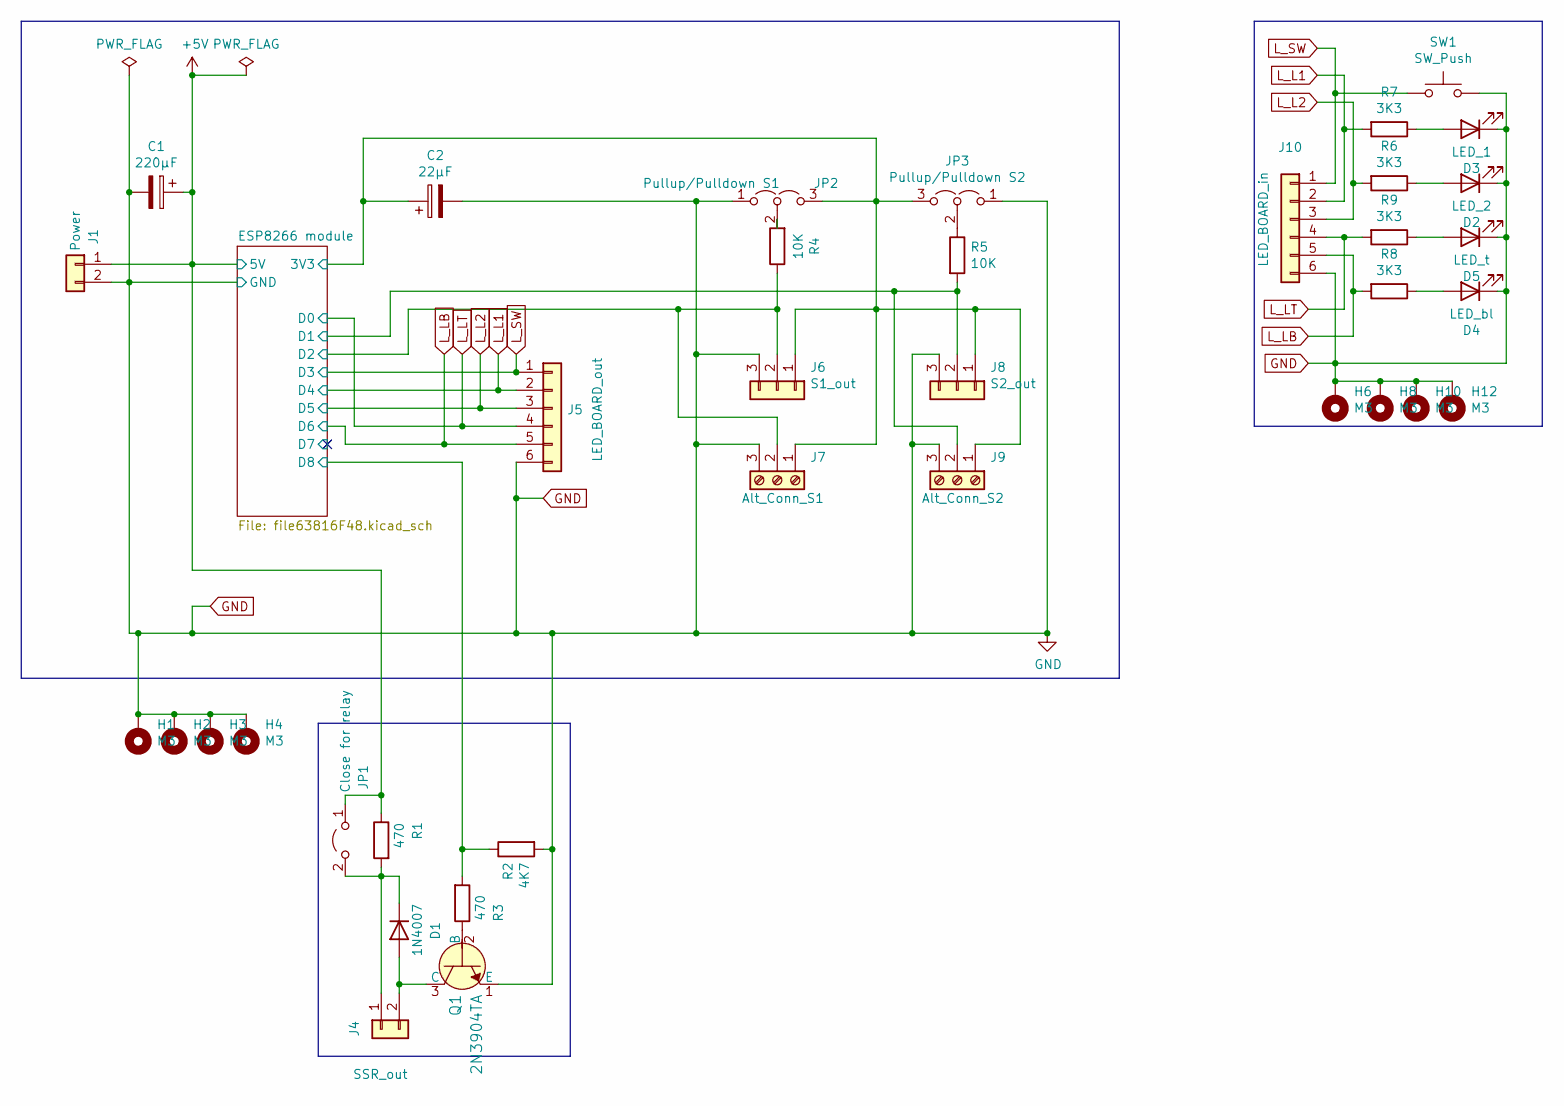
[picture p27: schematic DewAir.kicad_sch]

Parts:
C1: 220µF; CP_Radial_D5.0mm_P2.00mm
C2: 22µF; CP_Radial_D4.0mm_P2.00mm
D1: 1N4007; D_A-405_P7.62mm_Horizontal
D2: LED_2; LED_D3.0mm
D3: LED_1; LED_D3.0mm
D4: LED_bl; LED_D3.0mm
D5: LED_t; LED_D3.0mm
H1, H2, H3, H4, H6, H8, H10, H12: M3; MountingHole_3.2mm_M3_DIN965_Pad
J1: Power; TerminalBlock_bornier-2_P5.08mm
J4: SSR_out; TerminalBlock_bornier-2_P5.08mm
J5: LED_BOARD_out; Pin_Header_Straight_1x06_Pitch2.54mm
J6: S1_out; JST_XH_B03B-XH-A_03x2.50mm_Straight
J7: Alt_Conn_S1; TerminalBlock_bornier-3_P5.08mm
J8: S2_out; JST_XH_B03B-XH-A_03x2.50mm_Straight
J9: Alt_Conn_S2; TerminalBlock_bornier-3_P5.08mm
J10: LED_BOARD_in; Pin_Header_Straight_1x06_Pitch2.54mm
JP1: Close for relay; Pin_Header_Straight_1x02_Pitch2.54mm
JP2: Pullup/Pulldown S1; Pin_Header_Straight_1x03_Pitch2.54mm
JP3: Pullup/Pulldown S2; Pin_Header_Straight_1x03_Pitch2.54mm
Q1: 2N3904TA; TO-92_Inline; MPN 2N3904TA; Digi-Key_PN 2N3904TAFSCT-ND
R1, R3: 470; R_Axial_DIN0207_L6.3mm_D2.5mm_P7.62mm_Horizontal
R2: 4K7; R_Axial_DIN0207_L6.3mm_D2.5mm_P7.62mm_Horizontal
R4, R5: 10K; R_Axial_DIN0207_L6.3mm_D2.5mm_P7.62mm_Horizontal
R6, R7, R8, R9: 3K3; R_Axial_DIN0207_L6.3mm_D2.5mm_P7.62mm_Horizontal
SW1: SW_Push; SW_PUSH_6mm_h9.5mm

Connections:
+5V: C1.1, J1.1, JP1.1 (A), R1.1; also elsewhere on the board
/ESP8266 module/3V3: C2.1, J6.1, J7.1, J8.1, J9.1, JP2.3 (B), JP3.3 (B); also elsewhere on the board
/ESP8266 module/D1: J8.2, J9.2, R5.2; also elsewhere on the board
/ESP8266 module/D2: J6.2, J7.2, R4.1; also elsewhere on the board
/ESP8266 module/D8: R2.1, R3.2; also elsewhere on the board
GND: C1.2, C2.2, D2.1 (K), D3.1 (K), D4.1 (K), D5.1 (K), H1.1, H2.1, H3.1, H4.1, H6.1, H8.1, H10.1, H12.1, J1.2, J5.6, J6.3, J7.3, J8.3, J9.3, J10.6, JP2.1 (A), JP3.1 (A), Q1.1 (E), R2.2, SW1.2; also elsewhere on the board
L_L1: J5.2, J10.2, R7.2; also elsewhere on the board
L_L2: J5.3, J10.3, R6.2; also elsewhere on the board
L_LB: J5.5, J10.5, R8.2; also elsewhere on the board
L_LT: J5.4, J10.4, R9.2; also elsewhere on the board
L_SW: J5.1, J10.1, SW1.1; also elsewhere on the board
unnamed: D1.1 (K), J4.1, JP1.2 (B), R1.2
unnamed: D1.2 (A), J4.2, Q1.3 (C)
unnamed: D2.2 (A), R6.1
unnamed: D3.2 (A), R7.1
unnamed: D4.2 (A), R8.1
unnamed: D5.2 (A), R9.1
unnamed: JP2.2 (C), R4.2
unnamed: JP3.2 (C), R5.1
unnamed: Q1.2 (B), R3.1

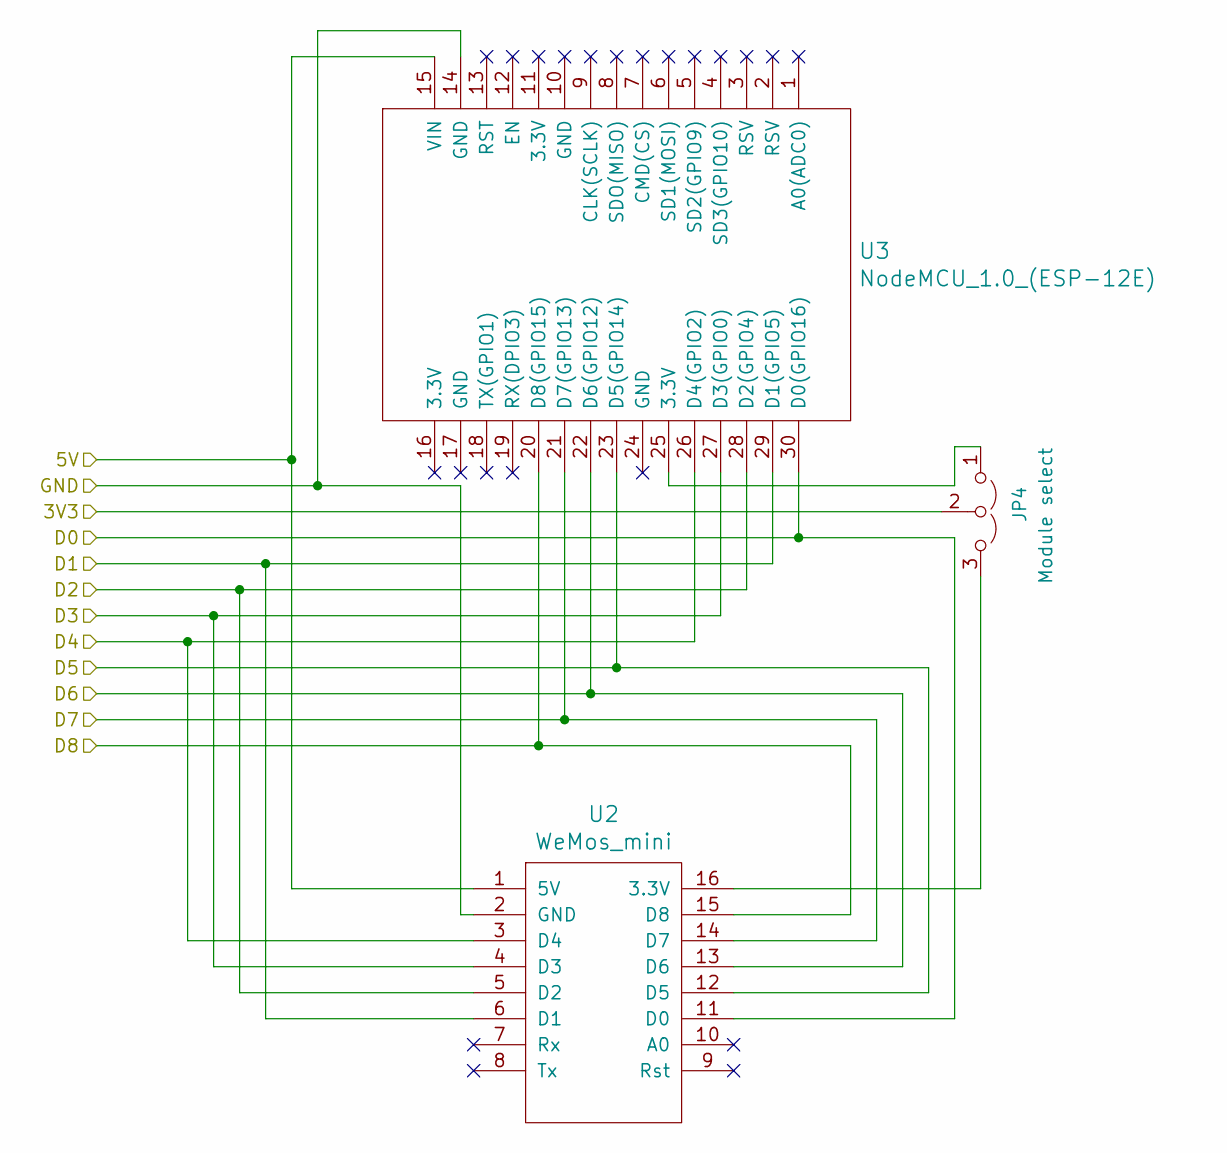
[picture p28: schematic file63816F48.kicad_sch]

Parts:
JP4: Module select; Pin_Header_Straight_1x03_Pitch2.54mm
U2: WeMos_mini; D1_mini_board
U3: NodeMCU_1.0_(ESP-12E); NodeMCU Amica

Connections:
+5V: U2.1 (5V), U3.15 (VIN); also elsewhere on the board
/ESP8266 module/3V3: JP4.2 (C); also elsewhere on the board
/ESP8266 module/D1: U2.6 (D1), U3.29 (D1(GPIO5)); also elsewhere on the board
/ESP8266 module/D2: U2.5 (D2), U3.28 (D2(GPIO4)); also elsewhere on the board
/ESP8266 module/D7: U2.14 (D7), U3.21 (D7(GPIO13))
/ESP8266 module/D8: U2.15 (D8), U3.20 (D8(GPIO15)); also elsewhere on the board
GND: U2.2 (GND), U3.14 (GND); also elsewhere on the board
L_L1: U2.3 (D4), U3.26 (D4(GPIO2)); also elsewhere on the board
L_L2: U2.12 (D5), U3.23 (D5(GPIO14)); also elsewhere on the board
L_LB: U2.13 (D6), U3.22 (D6(GPIO12)); also elsewhere on the board
L_LT: U2.11 (D0), U3.30 (D0(GPIO16)); also elsewhere on the board
L_SW: U2.4 (D3), U3.27 (D3(GPIO0)); also elsewhere on the board
unnamed: JP4.1 (A), U3.25 (3.3V)
unnamed: JP4.3 (B), U2.16 (3.3V)

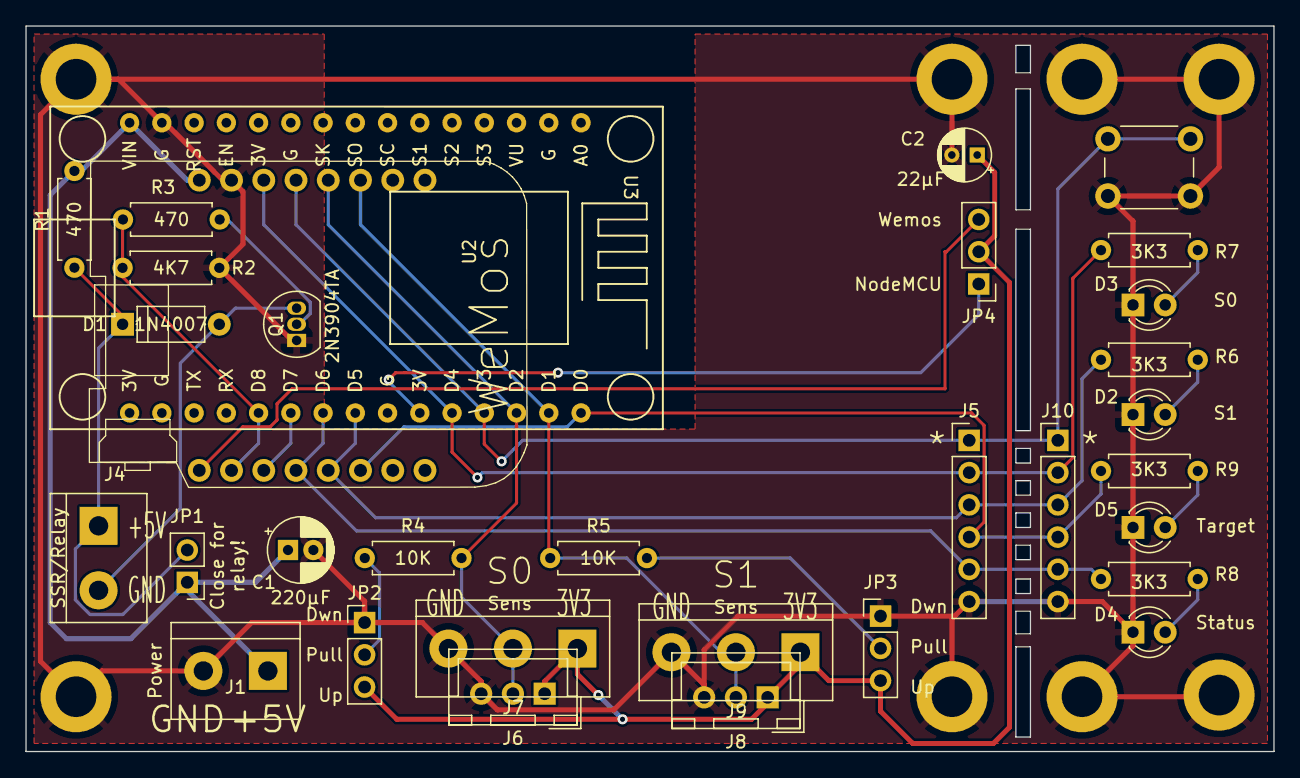
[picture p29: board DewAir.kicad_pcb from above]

Board: 2 copper layers, 98.3 x 57.1 mm, 40 parts (0 on the bottom side), 23 nets.

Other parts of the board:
H11: M3; MountingHole_3.2mm_M3_DIN965_Pad

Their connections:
GND: H11.1; also elsewhere on the board

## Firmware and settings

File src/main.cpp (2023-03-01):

// Copyright 2022 Michael Harwerth miq1 _ at _ gmx _ dot _ de

#include <Arduino.h>
#include <ESP8266WiFi.h>
#include <ArduinoOTA.h>
#include <ESPAsyncTCP.h>
#include <ESP8266mDNS.h>
#include <LittleFS.h>
#include <ESP8266WebServer.h>
#include "DHTesp.h"
#include "Version.h"
#include "Blinker.h"
#include "Buttoner.h"
#include "RingBuf.h"
#include "ModbusClientTCPAsync.h"
#include "ModbusServerTCPAsync.h"
#include "Logging.h"

// Pin definitions
#define SENSOR_0 D2
#define SENSOR_1 D1
#define SIGNAL_LED D6
#define S0STATUS_LED D4
#define S1STATUS_LED D5
#define TARGET_LED D0
#define SWITCH_PIN D3
#define TARGET_PIN D8

IPAddress myIP;               // local IP address
char AP_SSID[24];             // AP SSID for config mode
// Runtime modes
enum MODE_T : uint8_t { RUN, CONFIG, MANUAL };
MODE_T mode = RUN;
uint16_t runTime = 0;

// NTP definitions
#ifndef MY_NTP_SERVER
#define MY_NTP_SERVER "pool.ntp.org"
#endif
#ifndef MY_TZ
#define MY_TZ "CET"
#endif

// Milliseconds between measurements
uint32_t INTERVAL_DHT = 20000;

// Web server definitions
ESP8266WebServer HTMLserver(80);
#define SET_JS "/set.js"
#define CONFIG_HTML "/config.html"
#define SETTINGS "/settings.bin"
#define RESTARTS "/restarts.bin"
String deviceInfo(1024);

// Target address for Modbus device
struct ModbusTarget {
  uint32_t ip;
  uint16_t port;
  uint8_t serverID;
  uint8_t isValid;
  ModbusTarget() : ip(0), port(0), serverID(0), isValid(0) {}
};

// Switch hysteresis: only if a sequence of n measurements is identical, a switch action is considered
uint16_t Hysteresis = 0xAAAA;                               // holds last 16 results
uint16_t HYSTERESIS_MASK = 0x000F;                          // Bit mask to check last n measurements
uint16_t cState = 0;                                        // last evaluation result for switching conditions

// Target tracking
uint16_t targetHealth = 0;
bool switchedON = false;                                    // Current target switch state
// Modbus Error tracking
struct TT {
  Modbus::Error err;                                        // Error proper
  uint16_t count;                                           // Number of consecutive occurrences
  TT() : err(SUCCESS), count(0) {}
};
const uint16_t TTslots(30);                                 // Number of error groups tracked
uint16_t ttSlot{0};                                         // Currently active group
TT targetTrack[TTslots];                                    // Storage for error tracking

// Set up blink patterns for all 4 LEDs
Blinker signalLED(SIGNAL_LED);
Blinker S0LED(S0STATUS_LED);
Blinker S1LED(S1STATUS_LED);
Blinker targetLED(TARGET_LED);

// Blink pattern for "target ON": quick triple, pause
const uint16_t TARGET_ON_BLINK(0xA800);
// Blink pattern for "target OF": single, pause
const uint16_t TARGET_OFF_BLINK(0x1000);
// Wait for initial button press: quick on/off sequence, no pause
const uint16_t KNOB_BLINK(0x1111);
// CONFIG mode: long triple, pause
const uint16_t CONFIG_BLINK(0xCCC0);
// Wifi connect mode: long on/off, no pause
const uint16_t WIFI_BLINK(0xFF00);
// Manual mode: steady on
const uint16_t MANUAL_BLINK(0xFFFF);
// Device ignored: steady off
const uint16_t DEVICE_IGNORED(0x0000);
// Device OK: steady on
const uint16_t DEVICE_OK(0xFFFF);
// Device error: even quicker on/off sequence, no pause
const uint16_t DEVICE_ERROR_BLINK(0xAAAA);

// Switch to trigger restarts etc.
Buttoner tSwitch(SWITCH_PIN, LOW);

// Flag for remote reboot request
uint8_t rebootPending = 0;                // if != 0, reboot is awaiting second request
long unsigned int rebootGrace = 0;        // Wait timer for confirming second reboot request

// Two DHT sensors. In setup() will be found out if both are connected
struct mySensor {
  DHTesp sensor;                               // DHT object
  TempAndHumidity th;                          // Measured values
  float dewPoint;                              // Calculated from measurement
  Blinker& statusLED;
  uint16_t healthTracker;
  uint8_t sensor01;                            // Slot 0 or 1
  bool isRelevant;
  bool lastCheckOK;
  mySensor(Blinker& sLED, uint8_t whichOne) : 
    statusLED(sLED), 
    healthTracker(0), 
    sensor01(whichOne), 
    isRelevant(false),
    lastCheckOK(false) { }
};
mySensor DHT0(S0LED, 0);
mySensor DHT1(S1LED, 1);

// Choice list for target and sensor devices
enum DEVICEMODE : uint8_t { DEV_NONE=0, DEV_LOCAL, DEV_MODBUS, DEV_RESERVED };
// Choice list for conditions
enum DEVICECOND : uint8_t { DEVC_NONE=0, DEVC_LESS, DEVC_GREATER, DEVC_RESERVED };
// Defined class for IP port numbers to do proper error checking
class PORTNUM {
protected:
  uint16_t value;
public:
  PORTNUM() : value(0) {}
  explicit PORTNUM(uint16_t v) : value(v) {}
  operator uint16_t() { return value; }
  uint16_t operator=(uint16_t v) { return (value = v); }
};
// Defined class for Modbus server ID to do proper error checking
class SIDTYPE {
protected:
  uint8_t value;
public:
  SIDTYPE() : value(0) {}
  explicit SIDTYPE(uint8_t v) : value(v) {}
  operator uint8_t() { return value; }
  uint8_t operator=(uint8_t v) { return (value = v); }
};

// Settings data
const uint16_t MAGICVALUE(0x4716);
const uint8_t STRINGPARMLENGTH(32);
const uint8_t CONFIGPARAMS(48);
struct SetData {
  uint16_t magicValue;                   // 0x4712 upon successful initialization
  char deviceName[STRINGPARMLENGTH];     // CV0 Name of this device for mDNS, OTA etc.
  char WiFiSSID[STRINGPARMLENGTH];       // CV1 SSID of local WiFi
  char WiFiPASS[STRINGPARMLENGTH];       // CV2 Password for local WiFi
  char OTAPass[STRINGPARMLENGTH];        // CV3 OTA password
  bool masterSwitch;                     // CV4 Functions on/off main switch
  DEVICEMODE Target;                     // CV7 0=none, 1=local, 2=Modbus
  uint8_t hystSteps;                     // CV5 hysteresis step count 0..15 (16, 1..15)
  uint16_t measuringInterval;            // CV6 time between measurements in seconds
  IPAddress targetIP;                    // CV8..CV11 
  PORTNUM targetPort;                    // CV12 target Modbus port number
  SIDTYPE targetSID;                     // CV13 target Modbus server ID
  struct SensorData {
    DEVICEMODE type;                     // S0:CV14 S1:CV28 0=none, 1=local, 2=Modbus
    IPAddress IP;                        // S0:CV15..CV18 S1:CV29..CV32
    PORTNUM port;                        // S0:CV19 S1:CV33 Sensor Modbus port number
    SIDTYPE SID;                         // S0:CV20 S1:CV34 Sensor Modbus server ID
    bool slot;                           // S0:CV21 S1:CV35 Sensor Modbus slot: false=slot 1, true=slot 2
    DEVICECOND TempMode;                 // S0:CV22 S1:CV36 Sensor temperature condition 0:ignore, 1:<, 2:>
    float Temp;                          // S0:CV23 S1:CV37 Sensor condition temperature value
    DEVICECOND HumMode;                  // S0:CV24 S1:CV38 Sensor humidity condition 0:ignore, 1:<, 2:>
    float Hum;                           // S0:CV25 S1:CV39 Sensor condition humidity value
    DEVICECOND DewMode;                  // S0:CV26 S1:CV40 Sensor dew point condition 0:ignore, 1:<, 2:>
    float Dew;                           // S0:CV27 S1:CV41 Sensor condition dew point value
  } sensor[2];
  DEVICECOND TempDiff;                   // CV42 (S0 - S1) temperature condition 0:ignore, 1:<, 2:>
  float Temp;                            // CV43 (S0 - S1) condition temperature value
  DEVICECOND HumDiff;                    // CV44 (S0 - S1) humidity condition 0:ignore, 1:<, 2:>
  float Hum;                             // CV45 (S0 - S1) condition humidity value
  DEVICECOND DewDiff;                    // CV46 (S0 - S1) dew point condition 0:ignore, 1:<, 2:>
  float Dew;                             // CV47 (S0 - S1) condition dew point value
  bool fallbackSwitch;                   // CV48 Fallback if sensors etc. will fail
  SetData() {
    magicValue = 0;
  }
} settings;
uint16_t restarts;                     // number of reboots

// History data 
// Measurements are stored for 24h
const uint16_t HistorySlots(120);      // Number of measurements collected in 24h
const uint16_t HistoryAddress(400);    // Modbus register number of first history data
struct HistoryEntry {
  uint16_t temp0;                      // Sensor 0 temperature t0 as: uint16_t((t0 + 100.0) * 10.0) 
  uint16_t hum0;                       // Sensor 0 humidity h0 as: uint16_t(h0 * 10.0) 
  uint16_t temp1;                      // Sensor 1 temperature t1 as: uint16_t((t1 + 100.0) * 10.0) 
  uint16_t hum1;                       // Sensor 1 humidity h1 as: uint16_t(h1 * 10.0) 
  uint8_t on;                          // Target ON state as: (samples(ON) * 100) / samples
};
// Storage for history data
HistoryEntry history[HistorySlots];
// History evaluation struct
class CalcHistory {
protected:
  float t0sum;                         // Sum of all t0 values in a sampling period
  float h0sum;                         // Sum of all h0 values in a sampling period
  float t1sum;                         // Sum of all t0 values in a sampling period
  float h1sum;                         // Sum of all h0 values in a sampling period
  uint16_t onCnt;                      // Number of samples with target==ON
  uint16_t count;                      // Number of samples collected
  uint16_t historySlot;         // Current slot
  // reset: init counters
  void reset() {
    t0sum = h0sum = t1sum = h1sum = 0.0;
    onCnt = count = 0;
  }
  // push: move collected data into history slot
  void push(HistoryEntry& hE) {
    if (count) {
      hE.temp0 = (uint16_t)(((t0sum / count) + 100.0) * 10.0);
      hE.hum0 = (uint16_t)((h0sum / count) * 10.0);
      hE.temp1 = (uint16_t)(((t1sum / count) + 100.0) * 10.0);
      hE.hum1 = (uint16_t)((h1sum / count) * 10.0);
      hE.on = (uint8_t)((onCnt * 100) / count);
    }
  }
public:
  // Constructor
  CalcHistory() : historySlot(0) { reset(); }
  // calcSlot: determine history slot from hour and minute of current time
  static uint16_t calcSlot() {
    // We will need date and/or time
    time_t now = time(NULL);
    tm tm;
    localtime_r(&now, &tm);           // update the structure tm with the current time
    uint16_t minV = tm.tm_hour * 60 + tm.tm_min;    // Minute of day
    return HistorySlots ? minV / (1440 / HistorySlots) : 0;   // find slot
  }
  // collect: add another set of values
  uint16_t collect(float t0, float h0, float t1, float h1, bool on) {
    // get current slot
    uint16_t actSlot = calcSlot();
    // Has it changed?
    if (actSlot != historySlot) {
      // Yes. we need to move the collected data into history and adwance to the next
      push(history[historySlot]);
      historySlot = actSlot;
      reset();
    }
    count++;
    // If value is NaN or humidity is zero (unlikely...), do not use it, but promote the current average
    if (isnanf(t0) || h0 == 0.0) {
      t0sum += t0sum / count;
    } else {
      t0sum += t0;
    }
    // If value is NaN or humidity is zero (unlikely...), do not use it, but promote the current average
    if (isnanf(h0) || h0 == 0.0) {
      h0sum += h0sum / count;
    } else {
      h0sum += h0;
    }
    // If value is NaN or humidity is zero (unlikely...), do not use it, but promote the current average
    if (isnanf(t1) || h1 == 0.0) {
      t1sum += t1sum / count;
    } else {
      t1sum += t1;
    }
    // If value is NaN or humidity is zero (unlikely...), do not use it, but promote the current average
    if (isnanf(h1) || h1 == 0.0) {
      h1sum += h1sum / count;
    } else {
      h1sum += h1;
    }
    onCnt += (on ? 1 : 0);
    return count;
  }
};
CalcHistory calcHistory;

// Write both SETTINGS and SET_JS files with current settings data
// Some helper functions first
void writeSetting(Print& st, const char *header, uint8_t num, uint8_t target) {
  st.printf("%s.CV%d.value=\"%u\";\n", header, num, target);
}

void writeSetting(Print& st, const char *header, uint8_t num, uint16_t target) {
  st.printf("%s.CV%d.value=\"%u\";\n", header, num, target);
}

void writeSetting(Print& st, const char *header, uint8_t num, DEVICEMODE target) {
  st.printf("%s.CV%d.value=\"%u\";\n", header, num, target);
}

void writeSetting(Print& st, const char *header, uint8_t num, DEVICECOND target) {
  st.printf("%s.CV%d.value=\"%u\";\n", header, num, target);
}

void writeSetting(Print& st, const char *header, uint8_t num, PORTNUM target) {
  st.printf("%s.CV%d.value=\"%u\";\n", header, num, uint16_t(target));
  st.printf("%s.CV%d.min=\"1\";\n", header, num);
  st.printf("%s.CV%d.max=\"65535\";\n", header, num);
  st.printf("%s.CV%d.size=\"9\";\n", header, num);
  st.printf("%s.CV%d.step=\"1\";\n", header, num);
}

void writeSetting(Print& st, const char *header, uint8_t num, SIDTYPE target) {
  st.printf("%s.CV%d.value=\"%u\";\n", header, num, uint8_t(target));
  st.printf("%s.CV%d.min=\"1\";\n", header, num);
  st.printf("%s.CV%d.max=\"247\";\n", header, num);
  st.printf("%s.CV%d.size=\"5\";\n", header, num);
  st.printf("%s.CV%d.step=\"1\";\n", header, num);
}
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
void loop() {
  // Timer for measurement cycle
  static uint32_t measure = millis();  
  // Timer for runtime counting
  static uint32_t tick = millis();
  // Results of last conditions check
  static uint8_t s1cond = 0;
  static uint8_t s2cond = 0;
  static uint8_t cccond = 0;
  // Counter for measurement failures
  static uint16_t failCnt = 0;

  // Keep track of blinking status LEDs and button presses
  signalLED.update();
  targetLED.update();
  S0LED.update();
  S1LED.update();

  // Update mDNS
  MDNS.update();

  // Check OTA requests
  ArduinoOTA.handle();

  // RUN mode?
  if (mode == RUN) {
    if (tSwitch.update() > 0) {
      // Button pressed?
      ButtonEvent be = tSwitch.getEvent();
      // Short press?
      if (be == BE_CLICK) {
        // Yes, single click. Check sensors again
        checkSensor(DHT0);
        checkSensor(DHT1);
      } else if (be == BE_PRESS) {
        // No, button was held. Switch to manual mode
        signalLED.start(MANUAL_BLINK);
        S0LED.stop();
        S1LED.stop();
        targetLED.stop();
        mode = MANUAL;
        registerEvent(ENTER_MAN);
      } else if (be == BE_DOUBLECLICK) {
        // No again, we caught a double click instead
        // Let the three device LEDs signal the switch logic calculations result
        // Will be normalized as soon as the next measuring cycle is begun.
        // Sensor 0 all conditions met?
        if (s1cond == 3) { S0LED.start(MANUAL_BLINK);  // Yes, LED steady on
        } else           { S0LED.stop(); }             // No, LED off
        // Sensor 1 all conditions met?
        if (s2cond == 3) { S1LED.start(MANUAL_BLINK);
        } else           { S1LED.stop(); }
        // Combined conditions all met?
        if (cccond == 3) { targetLED.start(MANUAL_BLINK);
        } else           { targetLED.stop(); }
      }
    }
  
    // Is it time to advance the runtime counter?
    // (do a target state check as well)
    if (millis() - tick >= 60000) {
      // Yes, increment it as long as it did not hit the ceiling yet
      if (runTime < 65535) {
        runTime++;
      }
      // Check for data change
      time_t now = time(NULL);
      tm tm;
      localtime_r(&now, &tm);           // update the structure tm with the current time
      if (tm.tm_hour == 0 && tm.tm_min == 0) {
        registerEvent(DATE_CHANGE);
      }
      // Is a target configured?
      if (settings.Target != DEV_NONE) {
        // Yes. get switch state
        // Is it a Modbus device?
        if (settings.Target == DEV_MODBUS) {
          // Yes, send a request
          MBclient.setTarget(settings.targetIP, settings.targetPort);
          Error e = MBclient.addRequest((uint32_t)((millis() << 16) | 0x2008), settings.targetSID, READ_HOLD_REGISTER, 1, 1);
          if (e != SUCCESS) {
            ModbusError me(e);
            Serial.printf("Error sending request 0x2008: %02X - %s\n", e, (const char *)me);
            registerMBerror(e);
          }
          LOG_V("Switch status requested\n");
        } else {
          // No, shall be local
          // We must trust on the wiring, so we assume good health
          switchedON = digitalRead(TARGET_PIN);
          targetHealth <<= 1;
          targetHealth |= 1;
          // Toggle LED to show target switch state
          targetLED.start(switchedON ? DEVICE_OK : DEVICE_IGNORED);
        }
      }
      // Debug output
      LOG_V("Health tracker: S1=%04X S2=%04X Tg=%04X\n", DHT0.healthTracker, DHT1.healthTracker, targetHealth);
      // Reset timer
      tick = millis();
    }

    // Is it time to do another measurement?
    if (millis() - measure > INTERVAL_DHT) {
      //  Check switch conditions
      s1cond = 0;
      s2cond = 0;
      cccond = 0;
      // Kill oldest hysteresis bit
      Hysteresis <<= 1;
      // Check for valid measurements
      uint8_t measurementSuccess = 0;

      // Check both sensors
      for (uint8_t i = 0; i < 2; i++) {
        // Select sensor
        mySensor& sensor = (i == 0) ? DHT0 : DHT1;
        uint8_t& checks = (i == 0 ? s1cond : s2cond);
        // Keep in mind if the sensor is relevant at all
        sensor.isRelevant = (settings.sensor[i].TempMode != DEVC_NONE
              || settings.sensor[i].HumMode != DEVC_NONE
              || settings.sensor[i].DewMode != DEVC_NONE
              || settings.TempDiff != DEVC_NONE
              || settings.HumDiff != DEVC_NONE
              || settings.DewDiff != DEVC_NONE);

        // Do we need a measurement at all?
        if (settings.sensor[i].type != DEV_NONE) {
          // We do, check sensor.
          takeMeasurement(sensor);
          if (sensor.lastCheckOK) {
            measurementSuccess++;
          }
          // Is it relevant?
          if (sensor.isRelevant) {
            // Yes. Did we get data? (measurementSuccess will have been incremented already)
            if (sensor.lastCheckOK) {
              // Yes, we did.
              // 1: Check temperature
              switch (settings.sensor[i].TempMode) {
              case DEVC_NONE:  checks++; break;
              case DEVC_LESS:  if (sensor.th.temperature < settings.sensor[i].Temp) { checks++; } break;
              case DEVC_GREATER:  if (sensor.th.temperature > settings.sensor[i].Temp) { checks++; } break;
              case DEVC_RESERVED: break;
              }
              // 2: Check humidity
              switch (settings.sensor[i].HumMode) {
              case DEVC_NONE:  checks++; break;
              case DEVC_LESS:  if (sensor.th.humidity < settings.sensor[i].Hum) { checks++; } break;
              case DEVC_GREATER:  if (sensor.th.humidity > settings.sensor[i].Hum) { checks++; } break;
              case DEVC_RESERVED: break;
              }
              // 3: Check dew point
              switch (settings.sensor[i].DewMode) {
              case DEVC_NONE:  checks++; break;
              case DEVC_LESS:  if (sensor.dewPoint < settings.sensor[i].Dew) { checks++; } break;
              case DEVC_GREATER:  if (sensor.dewPoint > settings.sensor[i].Dew) { checks++; } break;
              case DEVC_RESERVED: break;
              }
            } else {
              // No, measurement has failed. Bail out here
              break;
            }
          } else {
            // It is irrelevant, so assume all conditions met
            checks = 3;
            // Additionally, no combo conditions will have to be met
            cccond = 3;
          }
        } else {
          // Sensor non-existent, assume all conditions met
          checks = 3;
          // Additionally, no combo conditions will have to be met
          cccond = 3;
          // Just in case clear previous LED signals
          sensor.statusLED.stop();
        }
      }

      // Finally check combo conditions
      // If we have one sensor only, no need to check
      if (cccond == 0) {
        // We have both sensors.
        // Did both measurements (if any) succeed?
        if (measurementSuccess == 2) {
          // Reset failure counter
          failCnt = 0;
          // Check temperature
          switch (settings.TempDiff) {
          case DEVC_NONE: cccond++; break;
          case DEVC_LESS: if (DHT0.th.temperature - DHT1.th.temperature < settings.Temp) { cccond++; } break;
          case DEVC_GREATER: if (DHT0.th.temperature - DHT1.th.temperature > settings.Temp) { cccond++; } break;
          case DEVC_RESERVED: break;
          }
          // Check humidity
          switch (settings.HumDiff) {
          case DEVC_NONE: cccond++; break;
          case DEVC_LESS: if (DHT0.th.humidity - DHT1.th.humidity < settings.Hum) { cccond++; } break;
          case DEVC_GREATER: if (DHT0.th.humidity - DHT1.th.humidity > settings.Hum) { cccond++; } break;
          case DEVC_RESERVED: break;
          }
          // Check dew point
          switch (settings.DewDiff) {
          case DEVC_NONE: cccond++; break;
          case DEVC_LESS: if (DHT0.dewPoint - DHT1.dewPoint < settings.Dew) { cccond++; } break;
          case DEVC_GREATER: if (DHT0.dewPoint - DHT1.dewPoint > settings.Dew) { cccond++; } break;
          case DEVC_RESERVED: break;
          }
        } else {
          // We failed for at least one sensor!
          failCnt++;
          if (failCnt > 3) {
            // Three failures in a row - fallback!
            switchTarget(settings.fallbackSwitch);
            registerEvent(FAIL_FB);
          }
        }
      }

      // Consider switching only if not in fail state
      if (failCnt == 0) {
        // All conditions met?
        if (s1cond + s2cond + cccond == 9) {
          Hysteresis |= 1;
        }
        // Store conditions for Modbus retrieval
        cState = (s1cond << 8) | (s2cond << 4) | cccond;
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

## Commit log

2022-10-19 Complete device info page
2022-10-20 Add Modbus FC 03. Correct time zone.
    [main.cpp]
2022-10-22 Fix relay pin, start documentation
    [main.cpp]
2022-10-26 Fix wrong comparison values
    [main.cpp]
2022-11-16 Fix some compiler warnings
    [main.cpp]
2022-12-14 Fix conditions evaluation w/ missing sensors
    [main.cpp]
2022-12-17 Fix LED assign and irrelevant sensor treatment
    [main.cpp]
2022-12-18 Add fallback switch option
2022-12-20 Fix logic for sensors connected, but irrelevant
    [main.cpp]
2022-12-30 Add case files
    [Dewair_klein_V2-Deckel.stl, Dewair_klein_V2-LED-Riser.stl, Dewair_klein_V2-Taste.stl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]
2022-12-30 Add German name of CAD file
2022-12-31 Add lid variants, Sensor housing and PCB files
    [DewAir.kicad_pcb, DewAir.kicad_sch, Dewair_klein_V2-Deckel_Hang.stl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]
2023-01-01 Different sensor housing
    [Sensor.FCStd, Sensor_Gehaeuse.stl]
2023-01-01 Make screw holes configurable
    [Dewair_klein_V2.FCStd]
2023-01-05 Prevent fallback for irrelevant sensor failures
    [main.cpp]
2023-01-05 Fix minor things with enclosures
    [Dewair_klein_V2.FCStd, Sensor.FCStd, Sensor_Gehaeuse.stl]
2023-01-05 Fix FreeCAD error message
    [Sensor.FCStd]
2023-01-06 Local target LED to reflect switch state
2023-01-13 Add fan window mount construction
    [Lüfterhalterung-Abdeckring.stl, Lüfterhalterung-Aussenkranz.stl, Lüfterhalterung-Bohrschablone.stl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]
2023-01-13 Change MB response handling to data/error
    [main.cpp]
2023-01-13 Add basic Modbus error log for target
    [main.cpp]
2023-01-24 Another rework of conditions logic
    [main.cpp]
2023-01-24 Add large enclosure
    [Dewair_gross.FCStd]
2023-01-26 Add updated large enclosure
    [Dewair_gross.FCStd, Dewair_gross_V2-Cover.stl, Dewair_gross_V2-Power lock.stl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]
2023-01-27 Fix minor stuff, add ventilation openings
    [Dewair_gross_V2-Cover.stl, Dewair_gross_V2.FCStd]
2023-02-05 Better Modbus sensor tracking
2023-02-18 Update 3D print parts and pictures
    [Lüfterhalterung-Schlauchadapter.stl, Lüfterhalterung.FCStd]
2023-02-28 Fix temperature encoding
2023-02-28 Fix typo (sensor 1 history)
    [main.cpp]
2023-02-28 Add current slot to Modbus registers
2023-03-02 Add slot marker to diagram
